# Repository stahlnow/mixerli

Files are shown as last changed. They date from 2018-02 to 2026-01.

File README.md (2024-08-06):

# mixerli

Battery powered 10 channel (4x2 + 1x2) stereo mixer featuring stereo input level control slider and stereo rotary aux send level control.

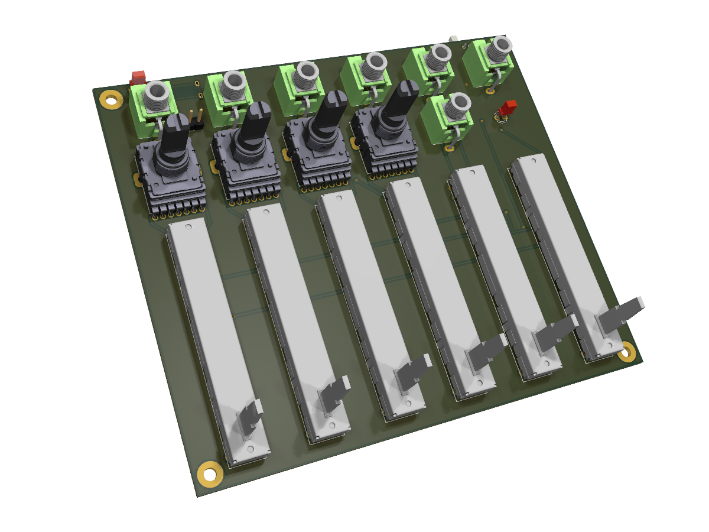
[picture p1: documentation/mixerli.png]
Mixerli


# Documentation

* [Build guide](documentation/build_guide.pdf)
* [Schematics](documentation/schematics/v2.0/mixerli_schematics_v2.0.1.pdf)

# License

SPDX-FileCopyrightText: 2023 Stahl office@stahlnow.com
SPDX-License-Identifier: CERN-OHL-S-2.0+

This source describes Open Hardware and is licensed under the CERN-OHL-S v2
or any later version.

You may redistribute and modify this source and make products using it
under the terms of the CERN-OHL-S v2 or any later version
(https://ohwr.org/cern_ohl_s_v2.txt).

This source is distributed WITHOUT ANY EXPRESS OR IMPLIED
WARRANTY, INCLUDING OF MERCHANTABILITY, SATISFACTORY
QUALITY AND FITNESS FOR A PARTICULAR PURPOSE. Please see
the CERN-OHL-S v2 for applicable conditions.

Source location: https://github.com/stahlnow/mixerli

As per CERN-OHL-S v2 section 4, should You produce hardware based
on this source, You must where practicable maintain the Source Location
visible on the printed circuit board of the mixerli or other products you make using this source.

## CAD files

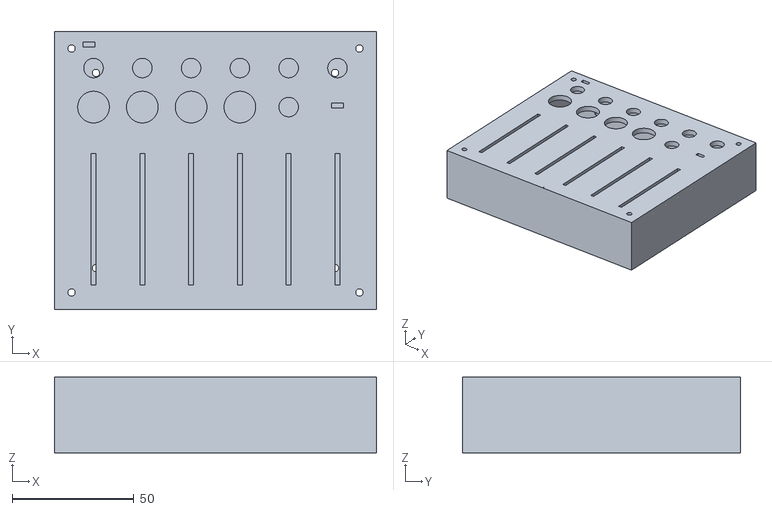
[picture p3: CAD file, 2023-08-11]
enclosure/v2.0/laser/mixerli_v2.0_case.stl
132.0 x 114.0 x 31.0

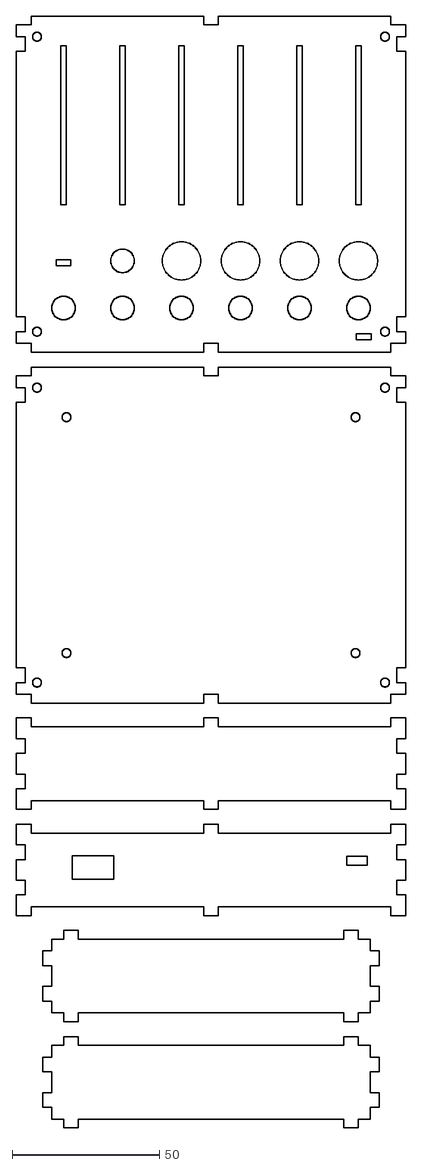
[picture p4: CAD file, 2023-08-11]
enclosure/v2.0/laser/output/mixerli_v2.0_case_laser_3mm.dxf
132.0 x 377.0

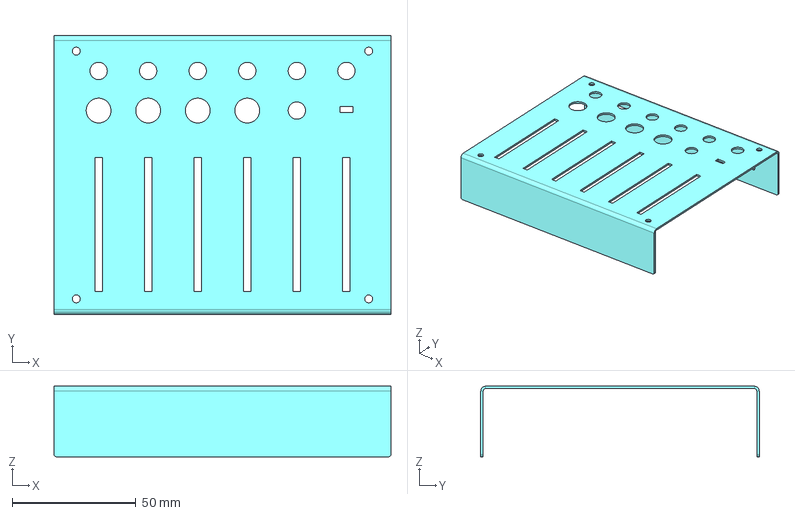
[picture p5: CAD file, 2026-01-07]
enclosure/v2.0/metalsheet/mixerli_v2.0.0-top.step
136.0 x 112.4 x 28.5 mm

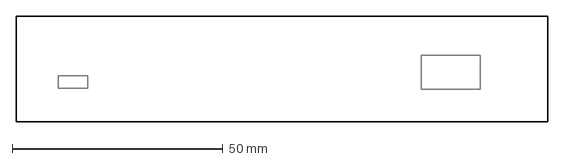
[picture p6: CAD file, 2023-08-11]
enclosure/v2.0/laser/mixerli_v2.0_back_cutout.dxf
126.0 x 25.0 mm

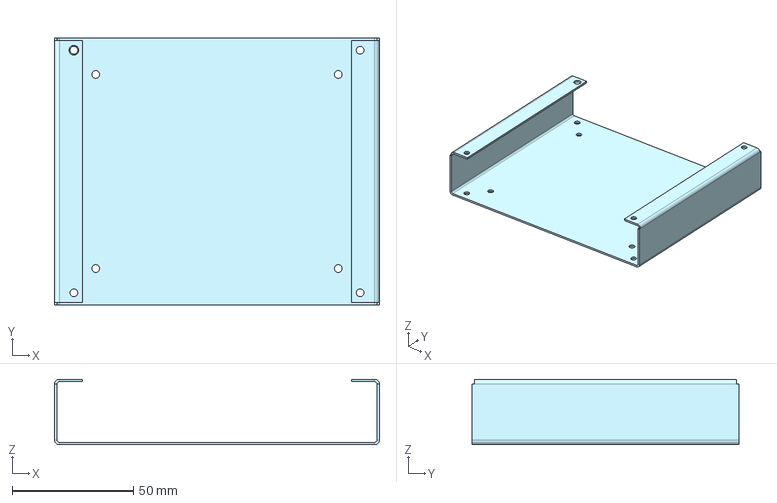
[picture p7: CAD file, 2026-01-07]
enclosure/v2.0/metalsheet/mixerli_v2.0.0-bottom.step
134.0 x 110.0 x 27.0 mm

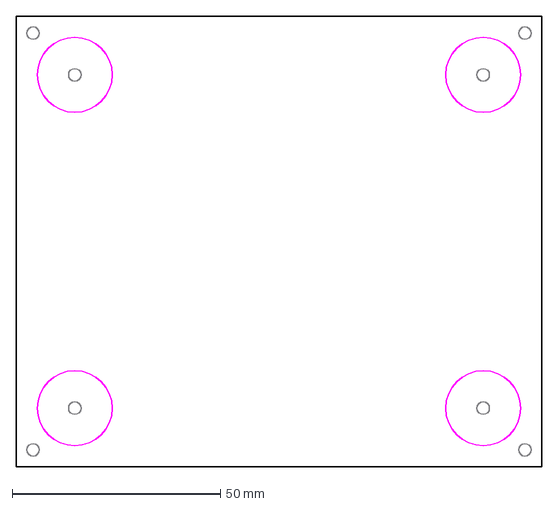
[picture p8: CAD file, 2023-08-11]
enclosure/v2.0/laser/mixerli_v2.0_bottom_cutout.dxf
126.0 x 108.0 mm

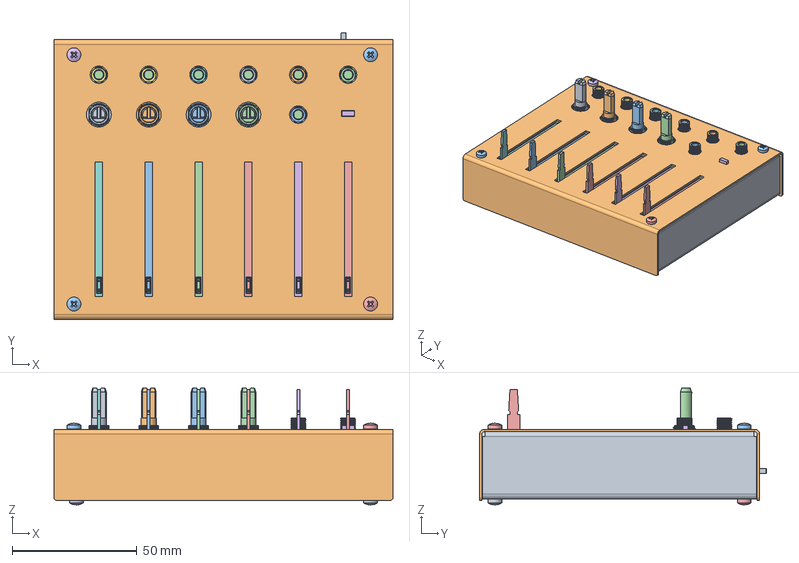
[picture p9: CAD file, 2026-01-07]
enclosure/v2.0/metalsheet/mixerli_v2.0.0.FCStd
136.0 x 115.1 x 46.9 mm
bottom
top
PJ366ST
PJ366ST002
ASSEMBLY
LED_Rectangular_W5.0mm_H2.0mm002
PJ366ST004
PJ366ST006
PJ366ST008
PJ366ST010
ASSEMBLY001
ASSEMBLY002
ASSEMBLY003
ASSEMBLY004
PJ366ST012
ASSEMBLY005
C_1206_3216Metric
C_1206_3216Metric002
C_1206_3216Metric004
C_1206_3216Metric006
C_1206_3216Metric008
C_1206_3216Metric010
C_1206_3216Metric012
CP_Elec_5x58
CP_Elec_5x059
C_1206_3216Metric014
C_1206_3216Metric016
C_1206_3216Metric018
C_1206_3216Metric020
CP_Elec_5x060
CP_Elec_5x061
CP_Elec_5x062
CP_Elec_5x063
C_1206_3216Metric022
C_1206_3216Metric024
C_1206_3216Metric026
C_1206_3216Metric028
C_1206_3216Metric030
C_1206_3216Metric032
CP_Elec_5x064
CP_Elec_5x065
C_1206_3216Metric034
C_1206_3216Metric036
C_1206_3216Metric038
C_1206_3216Metric040
CP_Elec_5x066
CP_Elec_5x067
C_1206_3216Metric042
C_1206_3216Metric044
C_1206_3216Metric046
C_1206_3216Metric048
CP_Elec_5x068
CP_Elec_5x069
C_1206_3216Metric050
C_1206_3216Metric052
C_1206_3216Metric054
C_1206_3216Metric056
C_1206_3216Metric058
C_1206_3216Metric060
R_1206_3216Metric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

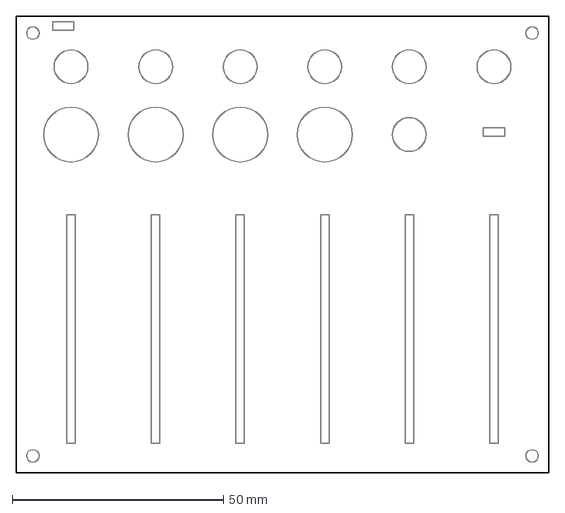
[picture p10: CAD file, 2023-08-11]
enclosure/v2.0/laser/mixerli_v2.0_top_cutout.dxf
126.0 x 108.0 mm

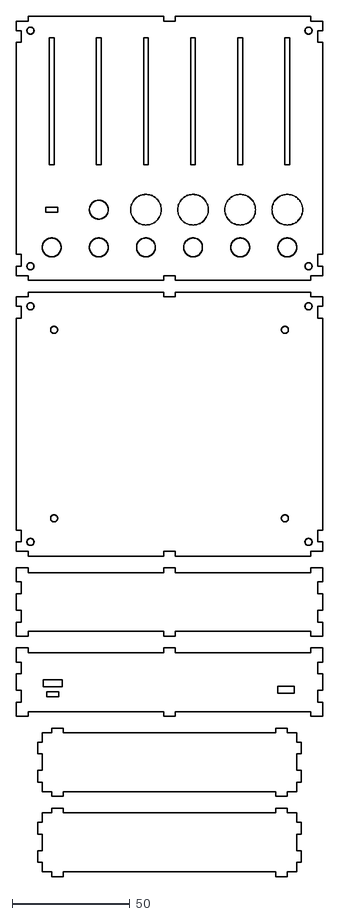
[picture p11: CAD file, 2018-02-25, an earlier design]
enclosure/v1.0/case/pocket_mixer_case_2mm.dxf
130.0 x 365.0

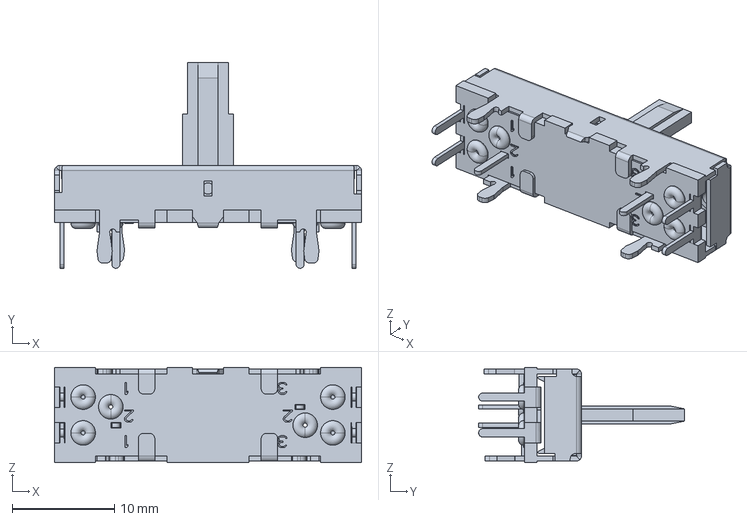
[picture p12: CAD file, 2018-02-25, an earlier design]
enclosure/v1.0/pta1544-2x10cixxxx.stp
30.0 x 20.1 x 9.30 mm

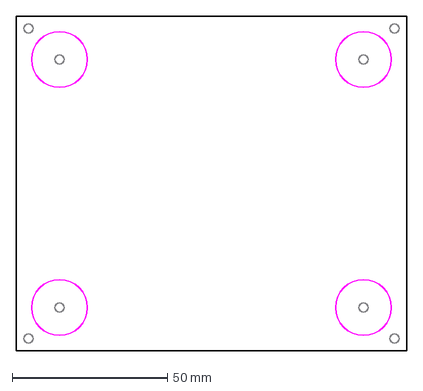
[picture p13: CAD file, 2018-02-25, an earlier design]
enclosure/v1.0/case/bottom_cutout.dxf
126.0 x 108.0 mm

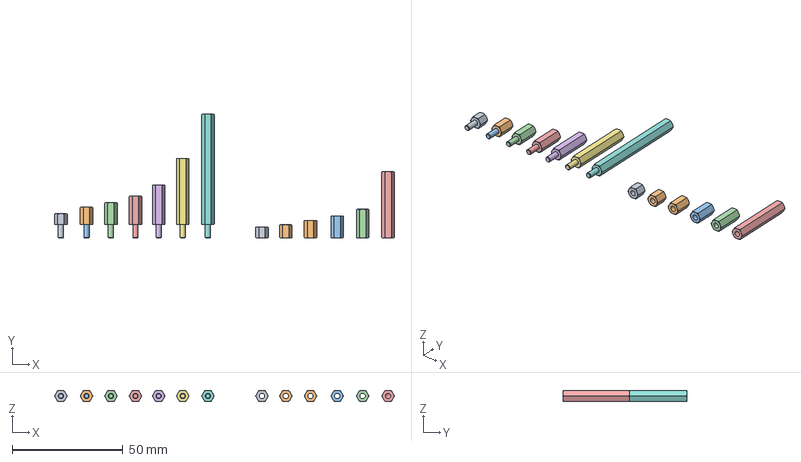
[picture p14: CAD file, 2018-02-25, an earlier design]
enclosure/v1.0/distans.stp
153.6 x 56.0 x 5.00 mm
OPT_DISTANSM3
DISTANSM3X10_VIDALI
DISTANSM3X10_VIDALI_1
DISTANSM3X10_VIDALI_2
DISTANSM3X18_VIDALI
DISTANSM3X30_VIDALI
DISTANSM3X50_VIDALI
DISTANSM3X5
DISTANSM3X10_VIDALI_3
DISTANSM3X10_VIDALI_4
DISTANSM3X10_VIDALI_5
DISTANSM3X10_VIDALI_6
DISTANSM3X30_DISI_DISI

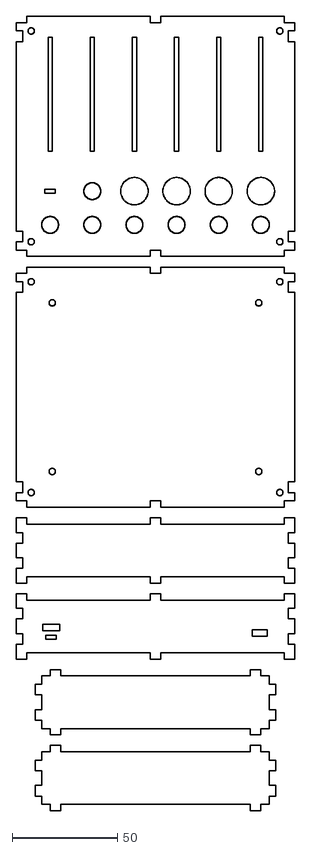
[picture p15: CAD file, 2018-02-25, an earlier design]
enclosure/v1.0/case/pocket_mixer_case_3mm.dxf
132.0 x 377.0

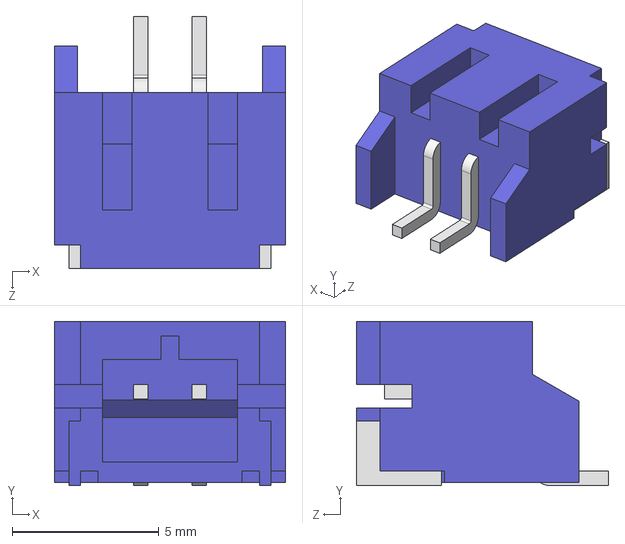
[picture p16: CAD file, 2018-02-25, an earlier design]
enclosure/v1.0/S2B-PH-SM4-TB.STEP
7.90 x 5.60 x 8.60 mm

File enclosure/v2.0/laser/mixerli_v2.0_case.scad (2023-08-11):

/*
mixer case
by stahl
[office@stahlnow.com]

released under the permissive MIT license

file history
v1.0 - born
*/

/*********************************************** START OF USER VARIABLES */
// what to build
laser = false;  // set to true for laser cut rendering
render(laser);

// define inner volume in mm
length = 108;
width = 126;
height = 25; // thing + spacer + extra space

thickness = 3; // thickness of material

// slots configuration
slots = true; // make slots?

// overlap of top/bottom panels in mm
overlap = 0;
// round edge or not (applies only if overlap > 0)
round_edges = true;

// slots configuration
num_slots_right_left = 2;       // number of slots >= 0
slot_width_right_left = 5;     // width of slot
slot_clearance_right_left = 4;  // inset to slot >= 0, add plus or minus 0.1 if last tooth is missing
num_slots_front_back = 3;       
slot_width_front_back = 5;
slot_clearance_front_back = 0.0;  // inset to slot >= 0, add plus or minus 0.1 if last tooth is missing

// t-joints configuration
t_joints_front = false;
t_joints_back = false;
t_joints_right = false;
t_joints_left = false;
t_joints_top_bottom = false;

num_t_joints = 1; // number of t-joints
bolt_size = 3; // bolt size in mm (M2,M3,M4,M5, etc.)
bolt_length = 13; // bolt length in mm

// clearence between panel edge and t-joint
// could be set to a number instead of calculation
t_joints_top_left_clearance = length/(2*num_t_joints); 
t_joints_right_left_clearance = height/(2*num_t_joints);
t_joints_front_back_clearance = width/(2*num_t_joints);

joints_inset = 2; // clearance between panel edge and hole
nut_size = 7.5;// M3: 5.5, M4: 7.2, M5: 8.0
nut_thickness = 3.5;// M3: 2.4, M4: 3.5 M5: 5.6

// clearance for laser cutting in mm
laser_clearance = 5;

// colors
col_alpha = 0.8;
col_top =  "DarkGrey";
col_bottom = "DarkGrey";
col_left = "Yellow";
col_right = col_left;
col_front = "LightBlue";
col_back = "Green";

// number of fragments for round edges
$fn = 100;

glitch_corr = 0.1; // visual glitch correction (careful, this will mess with dimensions!)

/************************************************* END OF USER VARIABLES */
module render(laser) {
    if (laser) {
        laser();
    } else {
        3d();
    }
}

module 3d() {
    /*
    color("Yellow", 0.9)
    rotate([0, 0, 0])
    translate([57.5, -20.5,2.5])
    import("mixerli_v2.0.stl");
    */
    
    top();
    bottom();
    front();
    back();
    left();
    right();
}

module laser() {
    glitch_corr = 0.0; // set glitch correction to zero
    // top
    rotate([0, 0, 180])
    if (slots) {
        projection() difference() {
            top();
            right();
            left();
            slots_front_back(-(length+thickness)/2.0);
            slots_front_back((length+thickness)/2.0);
        }
    } else {
        projection() mirror([1,0,0]) top();
    }

    // bottom
    bottom_offset = -(length+2*thickness+2*overlap+laser_clearance);
    translate([0,bottom_offset,0])
    rotate([0, 0, 180]) mirror([1,0,0])
    
    if (slots) {
        projection() difference() {
            bottom();
            right();
            left();        
            slots_front_back(-(length+thickness)/2.0);
            slots_front_back((length+thickness)/2.0);
        }
    } else {
        projection() bottom();
    }
    
    // front
    front_offset = bottom_offset-(length+height)/2-overlap-2*thickness-laser_clearance;
    projection() translate([0,front_offset,0]) rotate([-90,0,180])
    
    if (slots) {
        difference() {
            front();
            slots_right_left(-(width+thickness)/2);
            slots_right_left((width+thickness)/2);
        }
    } else {
        projection() front();
    }
    
    
    // back
    back_offset = front_offset-height-2*thickness-laser_clearance;
    projection() translate([0,back_offset,0]) rotate([-90,0,180]) mirror([1,0,0]) 
    if (slots) {
        difference() {
            back();
            slots_right_left(-(width+thickness)/2);
            slots_right_left((width+thickness)/2);
        }
    } else {
        projection() back();
    }

    // left
    left_offset = back_offset-height-2*thickness-laser_clearance;
    projection() translate([0,left_offset,0]) rotate([0,90,90]) left();
    
    // right
    right_offset = left_offset-height-2*thickness-laser_clearance;
    projection() translate([0,right_offset,0]) rotate([0,90,90]) right();
    
}


module top() {
    if (round_edges) {
        p = 0;
    } else {
        p = overlap;
    }
    
    difference() {
        union() color(col_top, col_alpha) {
            minkowski()
            {
                translate([0,0, (height+thickness)/2])
                if (!round_edges) {
                    cube([width+2*thickness+overlap, length+overlap+2*thickness, thickness-0.01], center=true);
                } else {
                    cube([width+2*thickness, length+2*thickness, thickness-0.01], center=true);
                }
                if (round_edges) cylinder(r=overlap, h=0.001, $fn=100);
            }
        }
        t_joints_holes_top_bottom();
        t_joints_holes_front_back();       
        // cutouts
        color("silver")
        translate([0.0, 0.0, (height-thickness)/2])
        linear_extrude(thickness*3)
        import(file = "mixerli_v2.0_top_cutout.dxf", layer = "0");
        // engraving
        color("white")
        translate([0.0, 0.0, height/2])
        linear_extrude(thickness)
        import(file = "mixerli_v2.0_top_cutout.dxf", layer = "engraving");
    }
}

module bottom() {
    if (round_edges) {
        p = 0;
    } else {
        p = overlap;
    }
    
    difference() {
        union() color(col_bottom, col_alpha) {
            minkowski()
            {
                translate([0,0, -(height+thickness)/2])
                if (!round_edges) {
                    cube([width+2*thickness+overlap, length+overlap+2*thickness, thickness-0.01], center=true);
                } else {
                    cube([width+2*thickness, length+2*thickness, thickness-0.01], center=true);
                }
                if (round_edges) cylinder(r=overlap, h=0.001, $fn=100);
            }
        }
        t_joints_holes_top_bottom();
        t_joints_holes_front_back();
        // cutouts
        color("silver")
        mirror([1,0,0]) translate([0.0, 0.0, -height/2-1.5*thickness])
        linear_extrude(thickness*2)
        import(file = "mixerli_v2.0_bottom_cutout.dxf", layer = "0");
        // engraving
        color("white")
        mirror([1,0,0]) translate([0.0, 0.0, -height/2-thickness])
        linear_extrude(thickness)
        import(file = "mixerli_v2.0_bottom_cutout.dxf", layer = "engraving");
    }
   
}

module front() { 
    difference() {
        union() color(col_front, col_alpha) {
            translate([0.0, -(length+thickness)/2.0, 0.0])
            cube([width+2.0*thickness, thickness, height], center=true);
            // slots
            if (slots)
                slots_front_back(-(length+thickness)/2.0);
        }
        
        // t-joints
        if (t_joints_front)
            t_joints_front_back(-(length+thickness)/2.0);
        // t-joints holes (on the side)
        t_joints_holes_right_left();
        
        // cutouts
        color("silver")
        translate([0,-length/2+thickness,0]) 
        rotate([90,0,0])
        linear_extrude(thickness*3)
        import(file = "mixerli_v2.0_front_cutout.dxf", layer = "0");
        // engraving
        color("white")
        translate([0,-length/2,0]) 
        rotate([90,0,0])
        linear_extrude(thickness)
        import(file = "mixerli_v2.0_front_cutout.dxf", layer = "engraving");        
    }
}

module back() {
    difference() {
        union()
        color(col_back, col_alpha) {
            translate([0.0, (length + thickness)/2.0, 0.0])
            cube([width+2.0*thickness, thickness, height], center=true);
            if (slots)
                slots_front_back((length+thickness)/2.0);
        }
        
        // t-joints
        if (t_joints_back)
            t_joints_front_back((length+thickness)/2.0);
        // t-joints holes (on the side)
        t_joints_holes_right_left();
        
        // cutouts
        color("silver")
        mirror([1,0,0]) rotate([90,0,0]) translate([0,0,-(length/2)-1.5*thickness]) 
        linear_extrude(thickness*2)
        import(file = "mixerli_v2.0_back_cutout.dxf", layer = "0");
        // engraving
        color("White")
        mirror([1,0,0]) rotate([90,0,0]) translate([0,0,-(length/2)-1.5*thickness]) 
        linear_extrude(thickness*3)
        import(file = "mixerli_v2.0_back_cutout.dxf", layer = "engraving");
    }
}

module t_joints_holes_right_left() {
    if (t_joints_left)
        t_joints_right_left(-(width+thickness)/2.0+joints_inset, true);
    if (t_joints_right)
        t_joints_right_left((width+thickness)/2.0-joints_inset, true);
}
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

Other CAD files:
enclosure/v1.0/case/top_cutout.dxf
enclosure/v1.0/case/back_cutout.dxf
enclosure/v1.0/Turn knob.STEP
enclosure/v1.0/1050170001.stp
enclosure/v1.0/case/pocket_mixer_case.scad

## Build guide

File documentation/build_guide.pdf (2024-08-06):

Battery powered 10 channel (4x2 + 1x2) stereo mixer featuring stereo input level control slider and stereo rotary aux send level control.

# Mixerli

Builder's Guide for v2.0
Source Location: github.com/stahlnow/mixerli

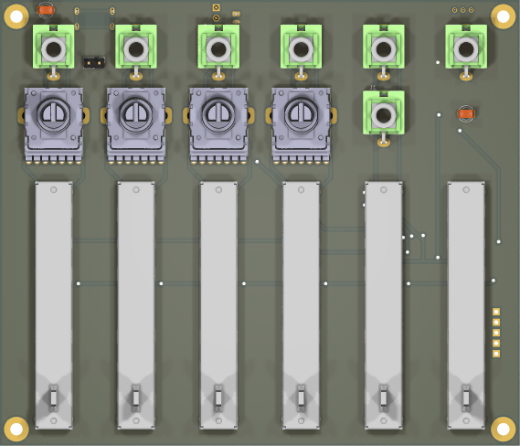
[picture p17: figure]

SPDX-FileCopyrightText: 2023 Stahl office@stahlnow.com SPDX-License-Identifier: CERN-OHL-S-2.0+

This source describes Open Hardware and is licensed under the CERN-OHL-S v2 or any later version.

You may redistribute and modify this source and make products using it under the terms of the CERN-OHL-S v2 or any later version (https://ohwr.org/cern_ohl_s_v2.txt).

This source is distributed WITHOUT ANY EXPRESS OR IMPLIED WARRANTY, INCLUDING OF MERCHANTABILITY, SATISFACTORY QUALITY AND FITNESS FOR A PARTICULAR PURPOSE. Please see the CERN-OHL-S v2 for applicable conditions.

Source location: https://github.com/stahlnow/mixerli

As per CERN-OHL-S v2 section 4, should You produce hardware based on this source, You must where practicable maintain the Source Location visible on the printed circuit board of the mixerli or other products you make using this source.

# Operation

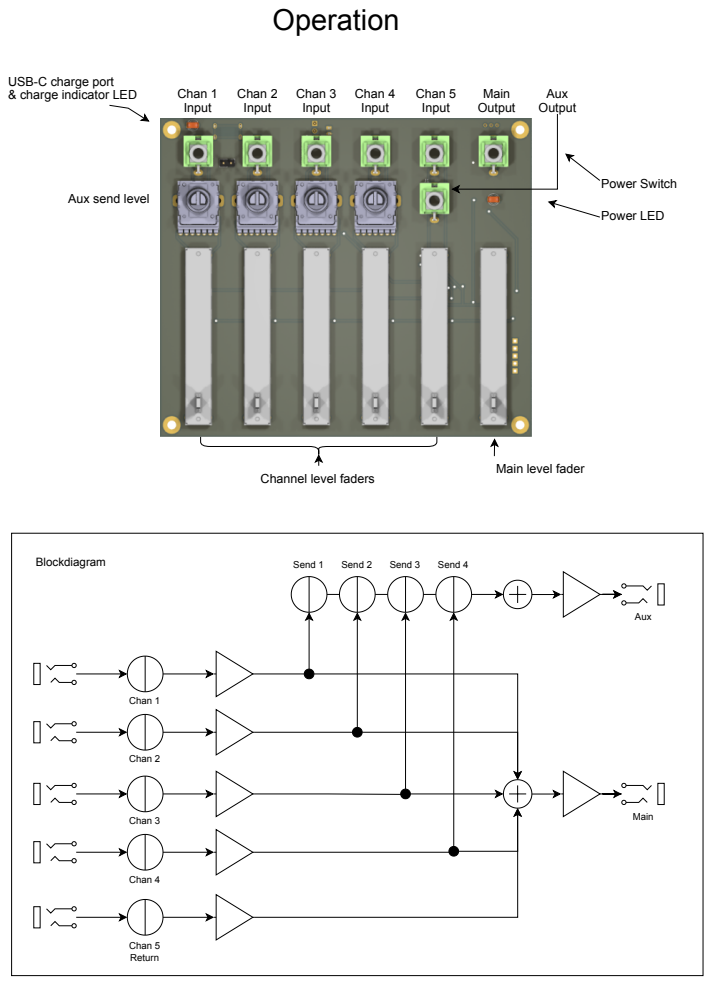
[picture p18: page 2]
Chan 1; Send 1; Chan 2; Send 2; Chan 3; Send 3; Chan 4; Send 4; Chan 5 Return; Aux; Main; Chan 5 Input; Power LED; Main Output; & charge indicator LED; Input; Chan 2 Input; Chan 3 Input; Chan 4 Input; Aux Output; Power Switch; Blockdiagram

USB-C charge port

Aux send level

Main level fader

Channel level faders

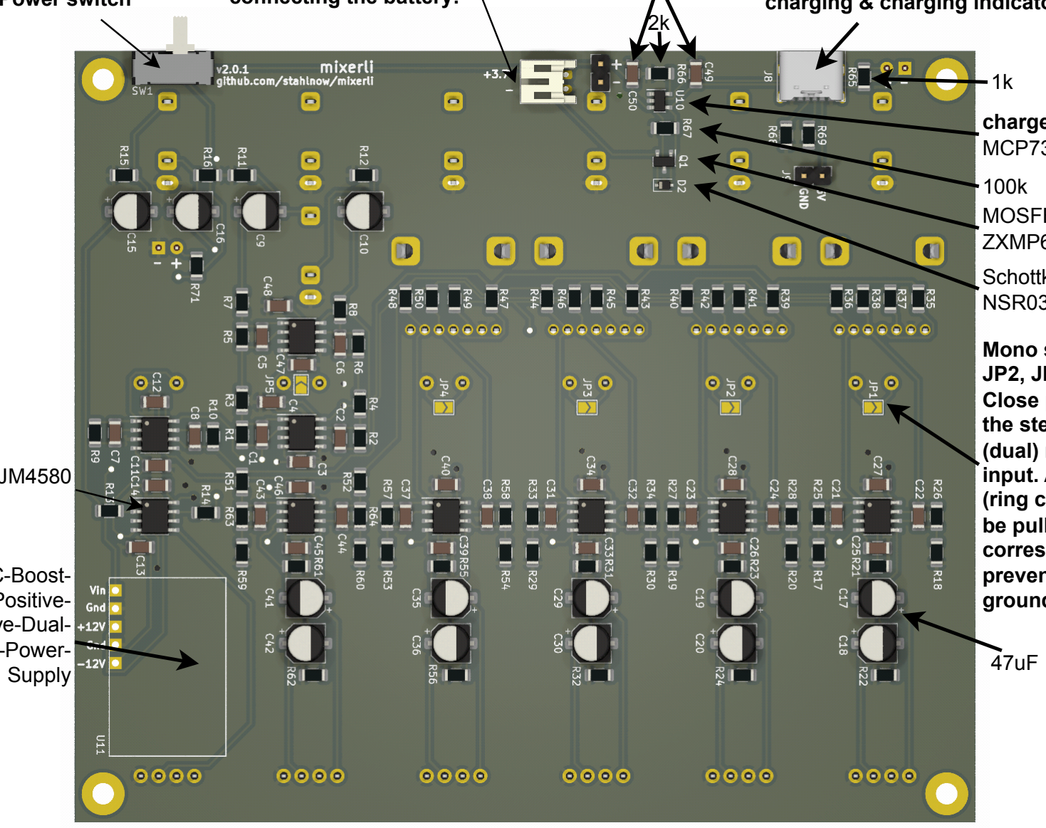
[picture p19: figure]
Supply

charge controller
MCP73831

Schottky diode
NSR0320MW2T3G

MOSFET
ZXMP6A13FTA

100k

4.7uF

1k

NJM4580

USB-C for powering and battery charging & charging indicator LED

Mono solder pads (JP1,
JP2, JP3, JP4):
Close pad X to convert
the stereo input X to a
(dual) monophonic
input. Additonally, pin 2
(ring contact) needs to
be pulled from the
corresponding jack to
prevent shorting to
ground.

DC-DC-Boost-Converter-Positive-Negative-Dual-Output-Power-

JST connector for battery. Connect to a 3.7v lithium polymer battery. Double check polarity before
Power switch | connecting the battery!

Please use ibom for easy pick & place.

# Build

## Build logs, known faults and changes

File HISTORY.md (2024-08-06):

# v2.0.1

- fixed pulldown resistors on CC lines

# v2.0.0

- usb c type connector
- power supply module
- new potentiometers and jacks

erratum

- power only works with USB type A cable, fix for type C cable: put 5.1k pulldown resistors on the two USB CC lines

# v1.0.0

- first version with μ usb

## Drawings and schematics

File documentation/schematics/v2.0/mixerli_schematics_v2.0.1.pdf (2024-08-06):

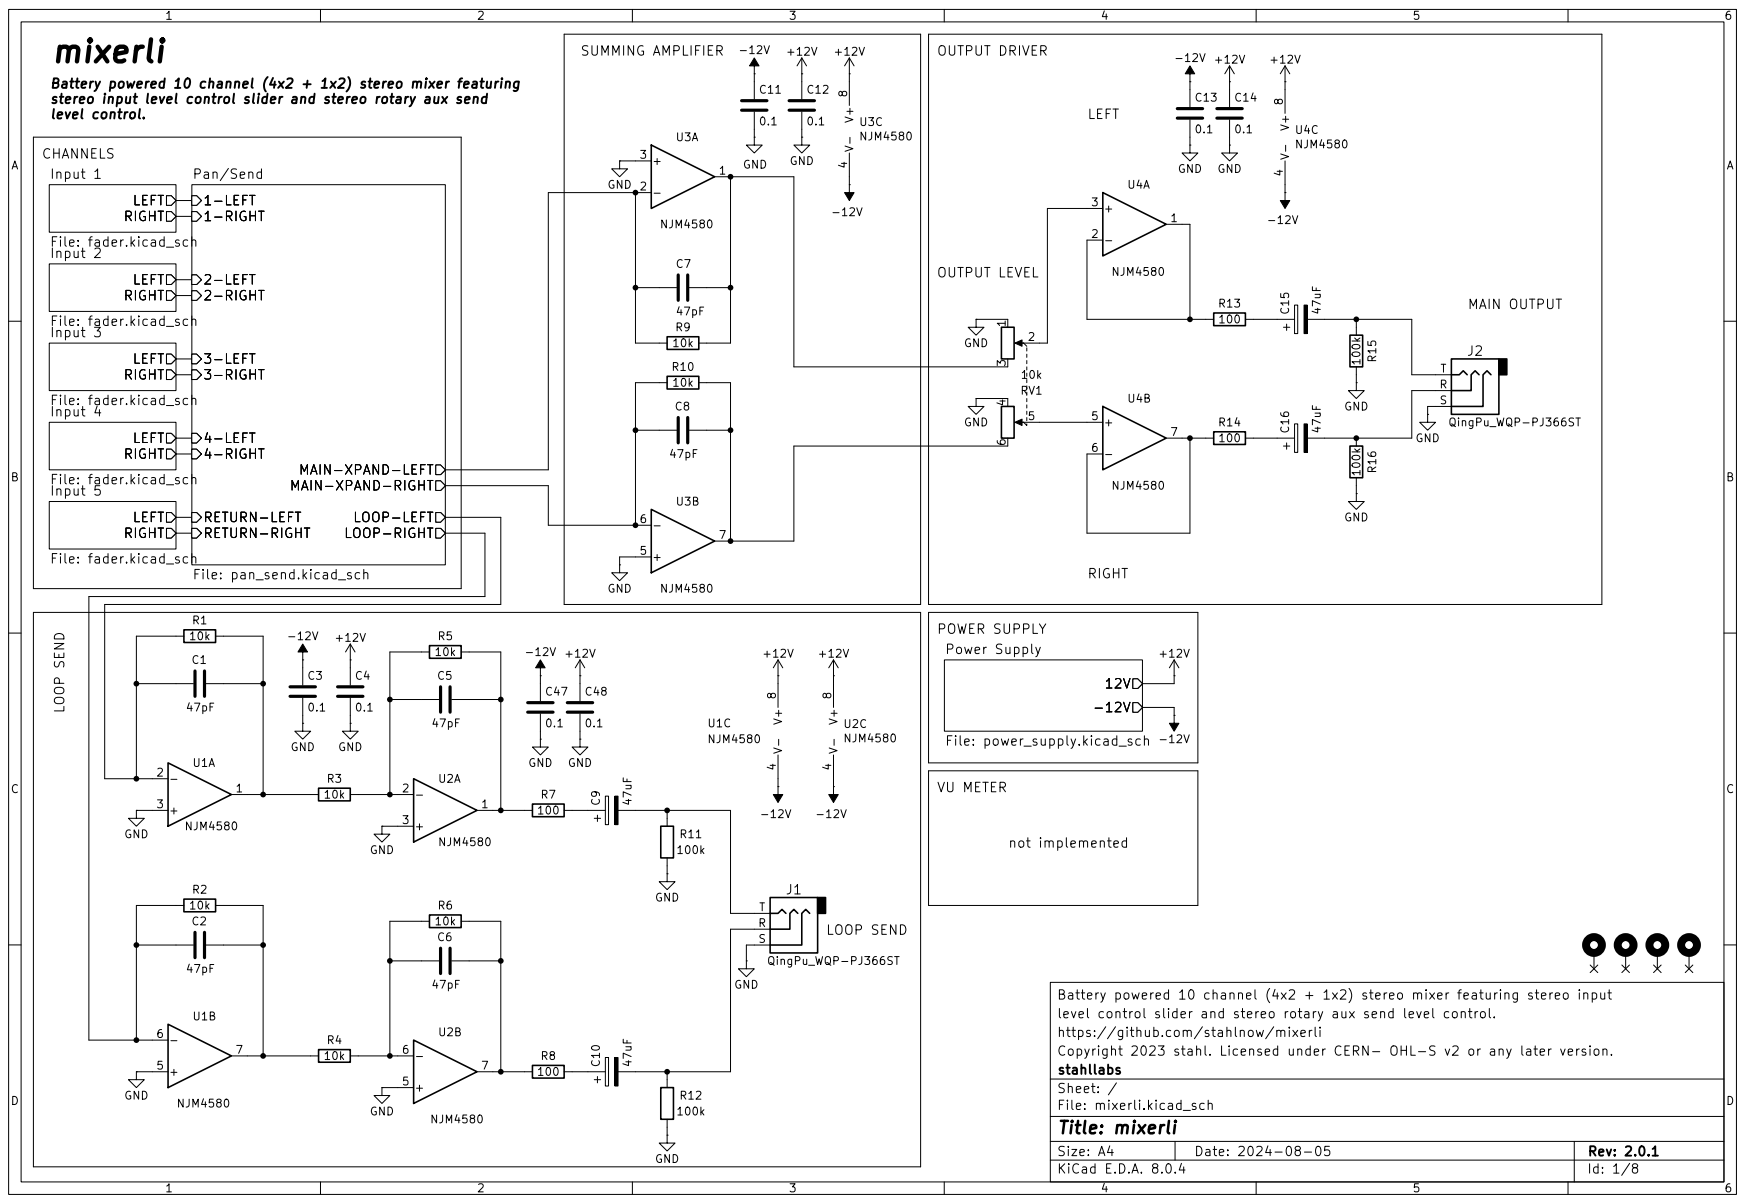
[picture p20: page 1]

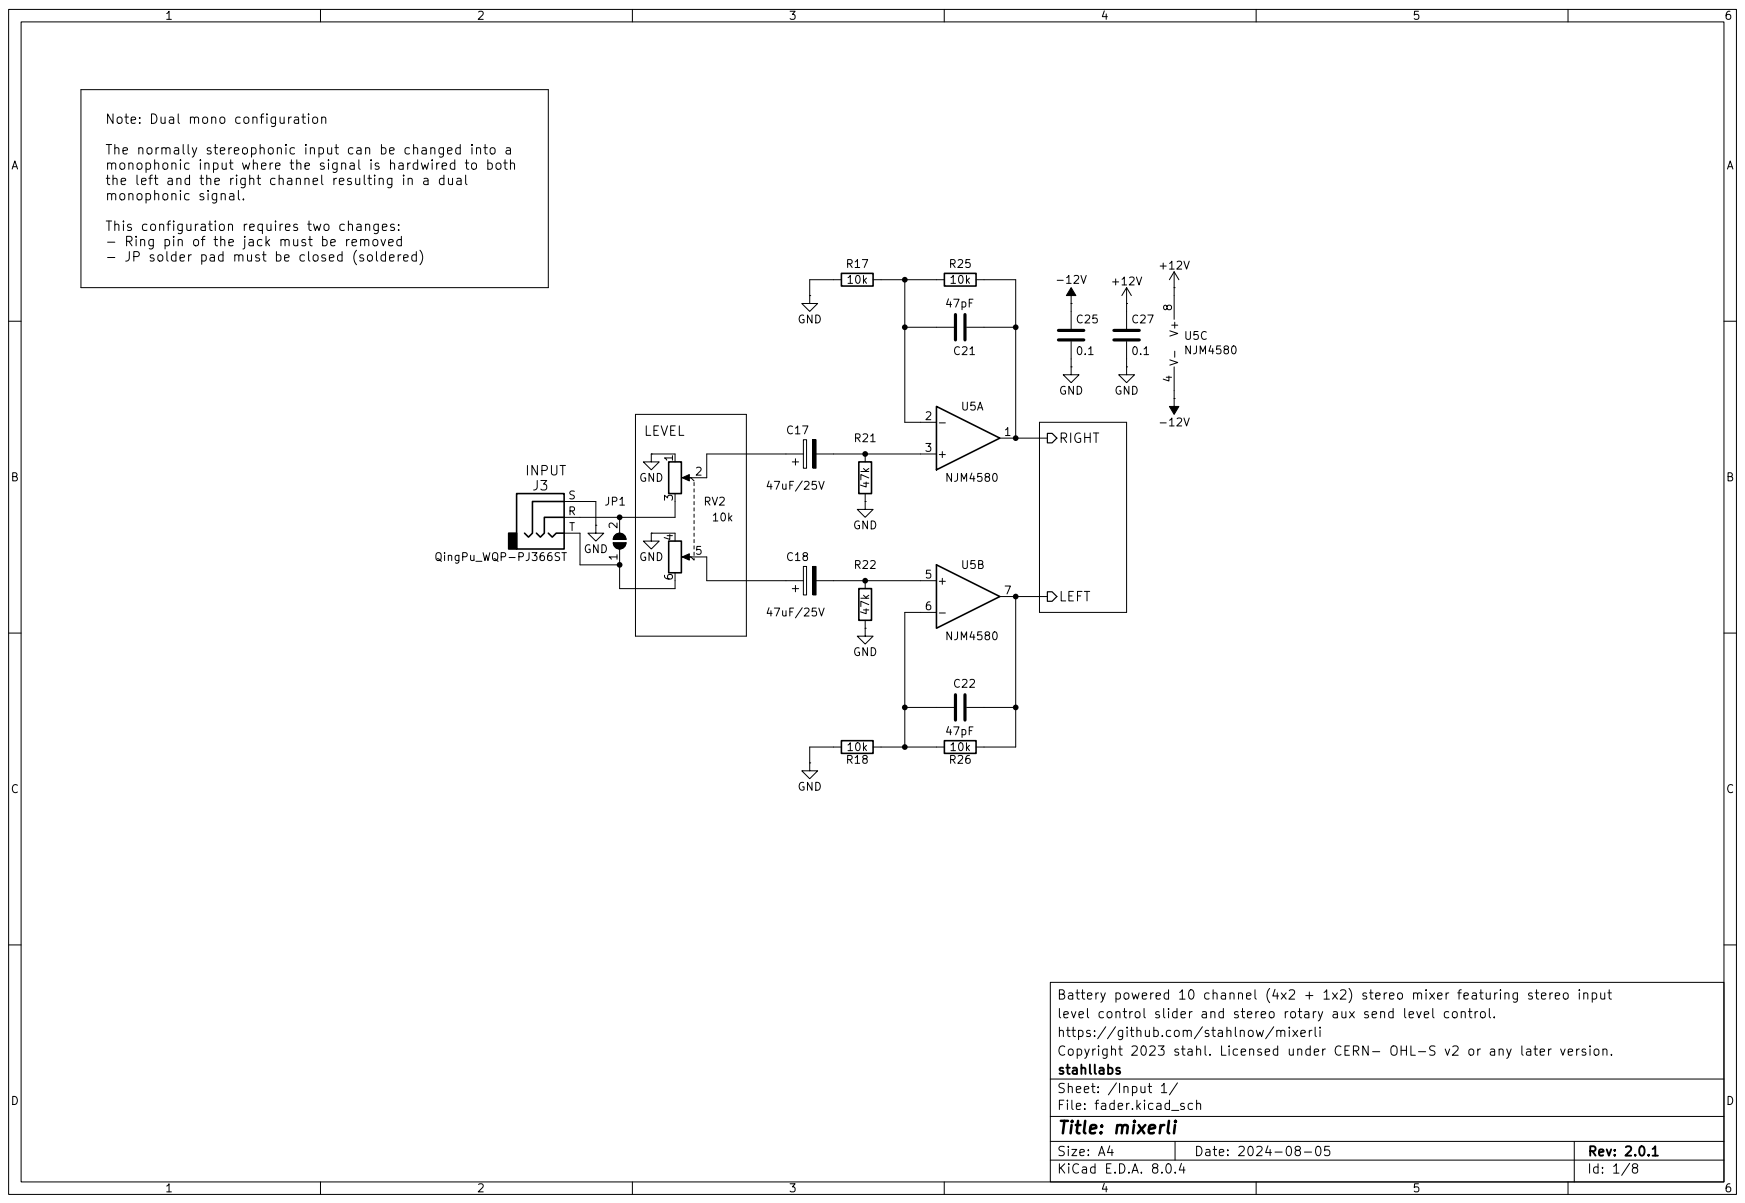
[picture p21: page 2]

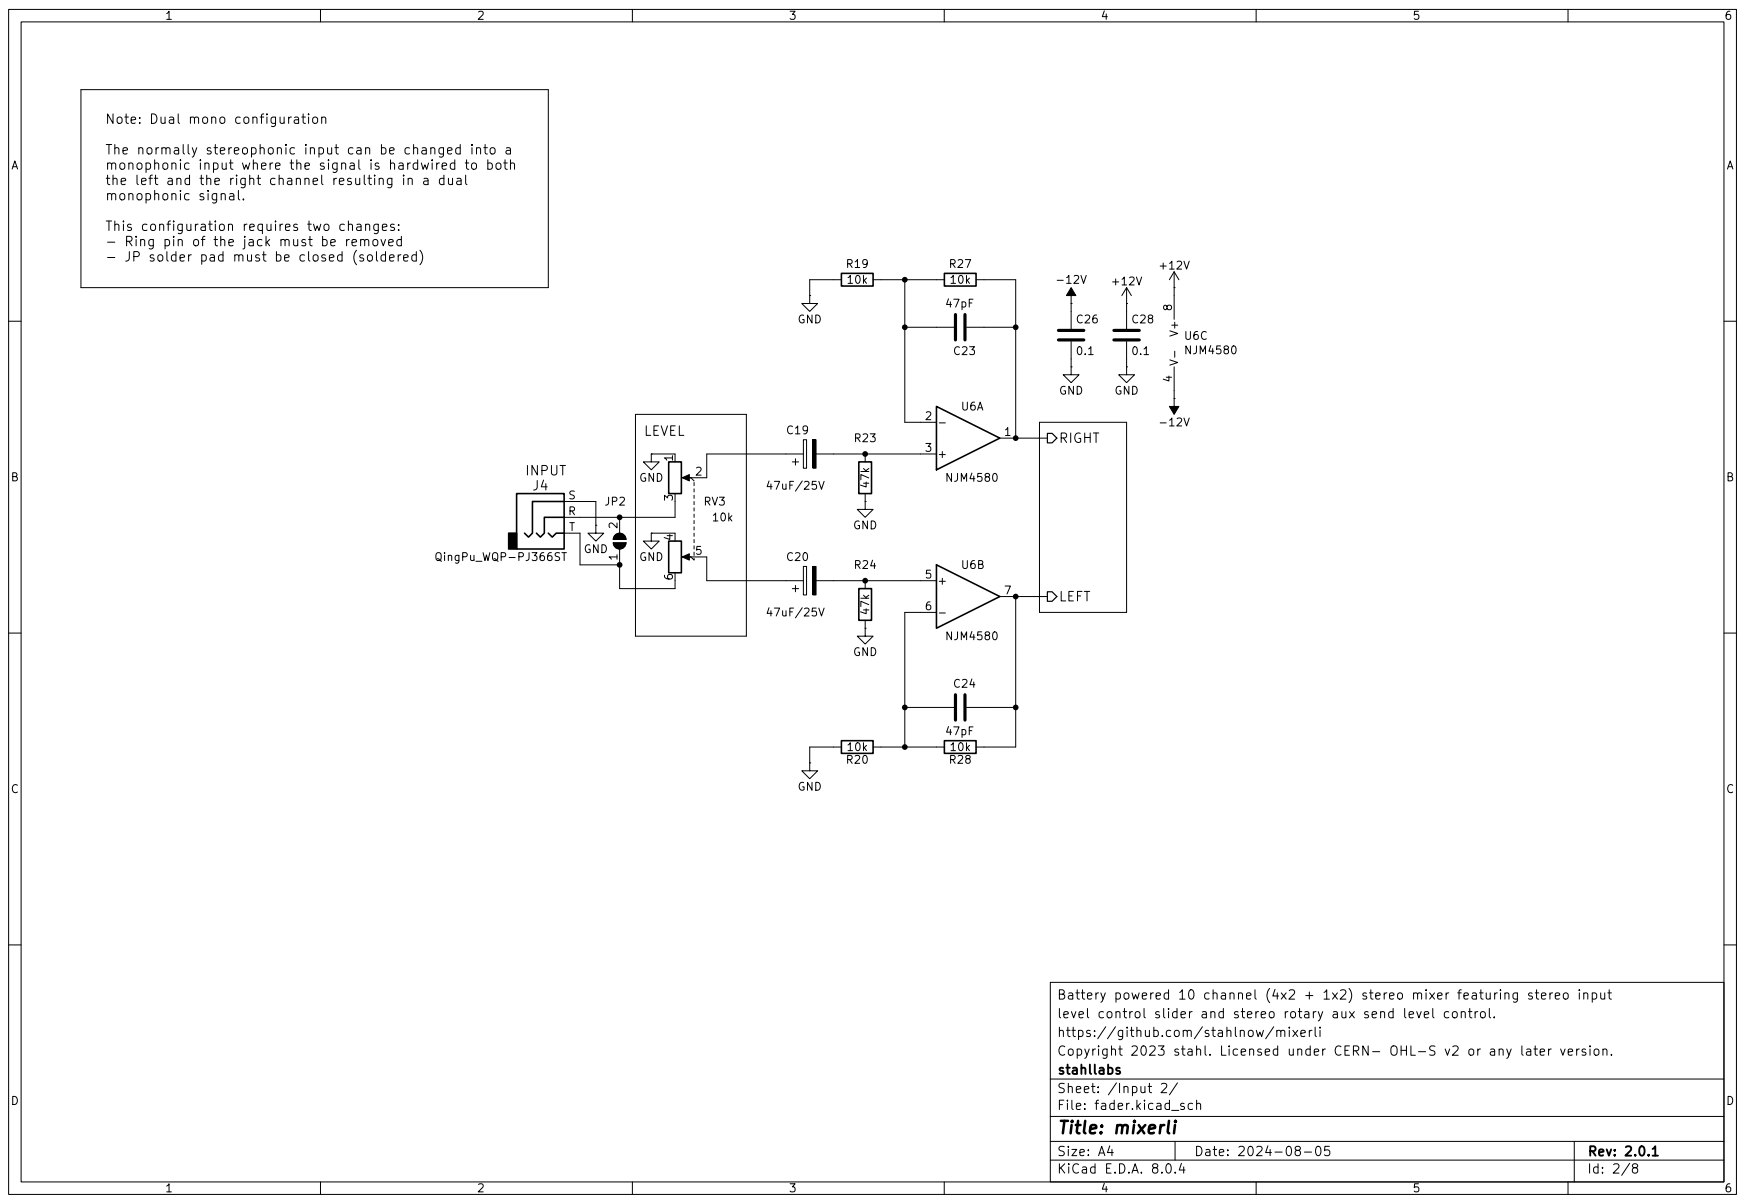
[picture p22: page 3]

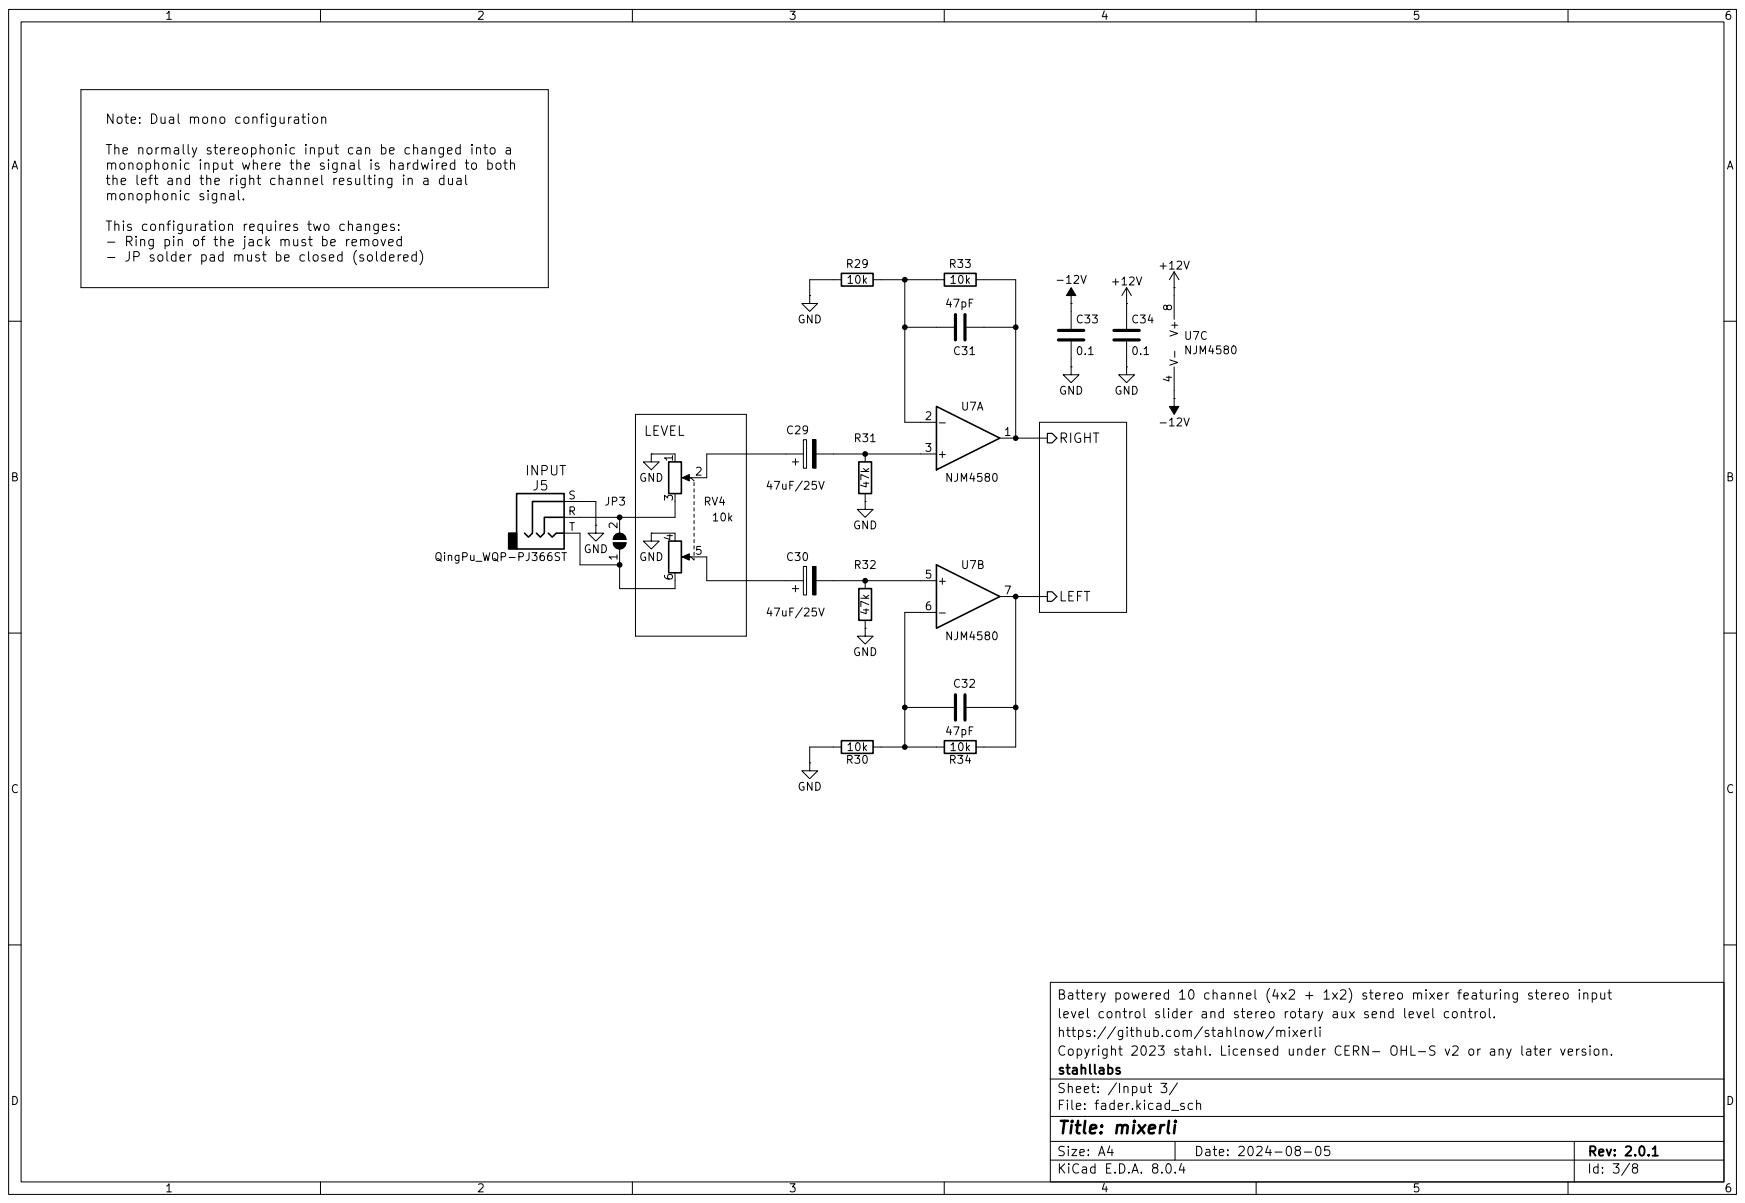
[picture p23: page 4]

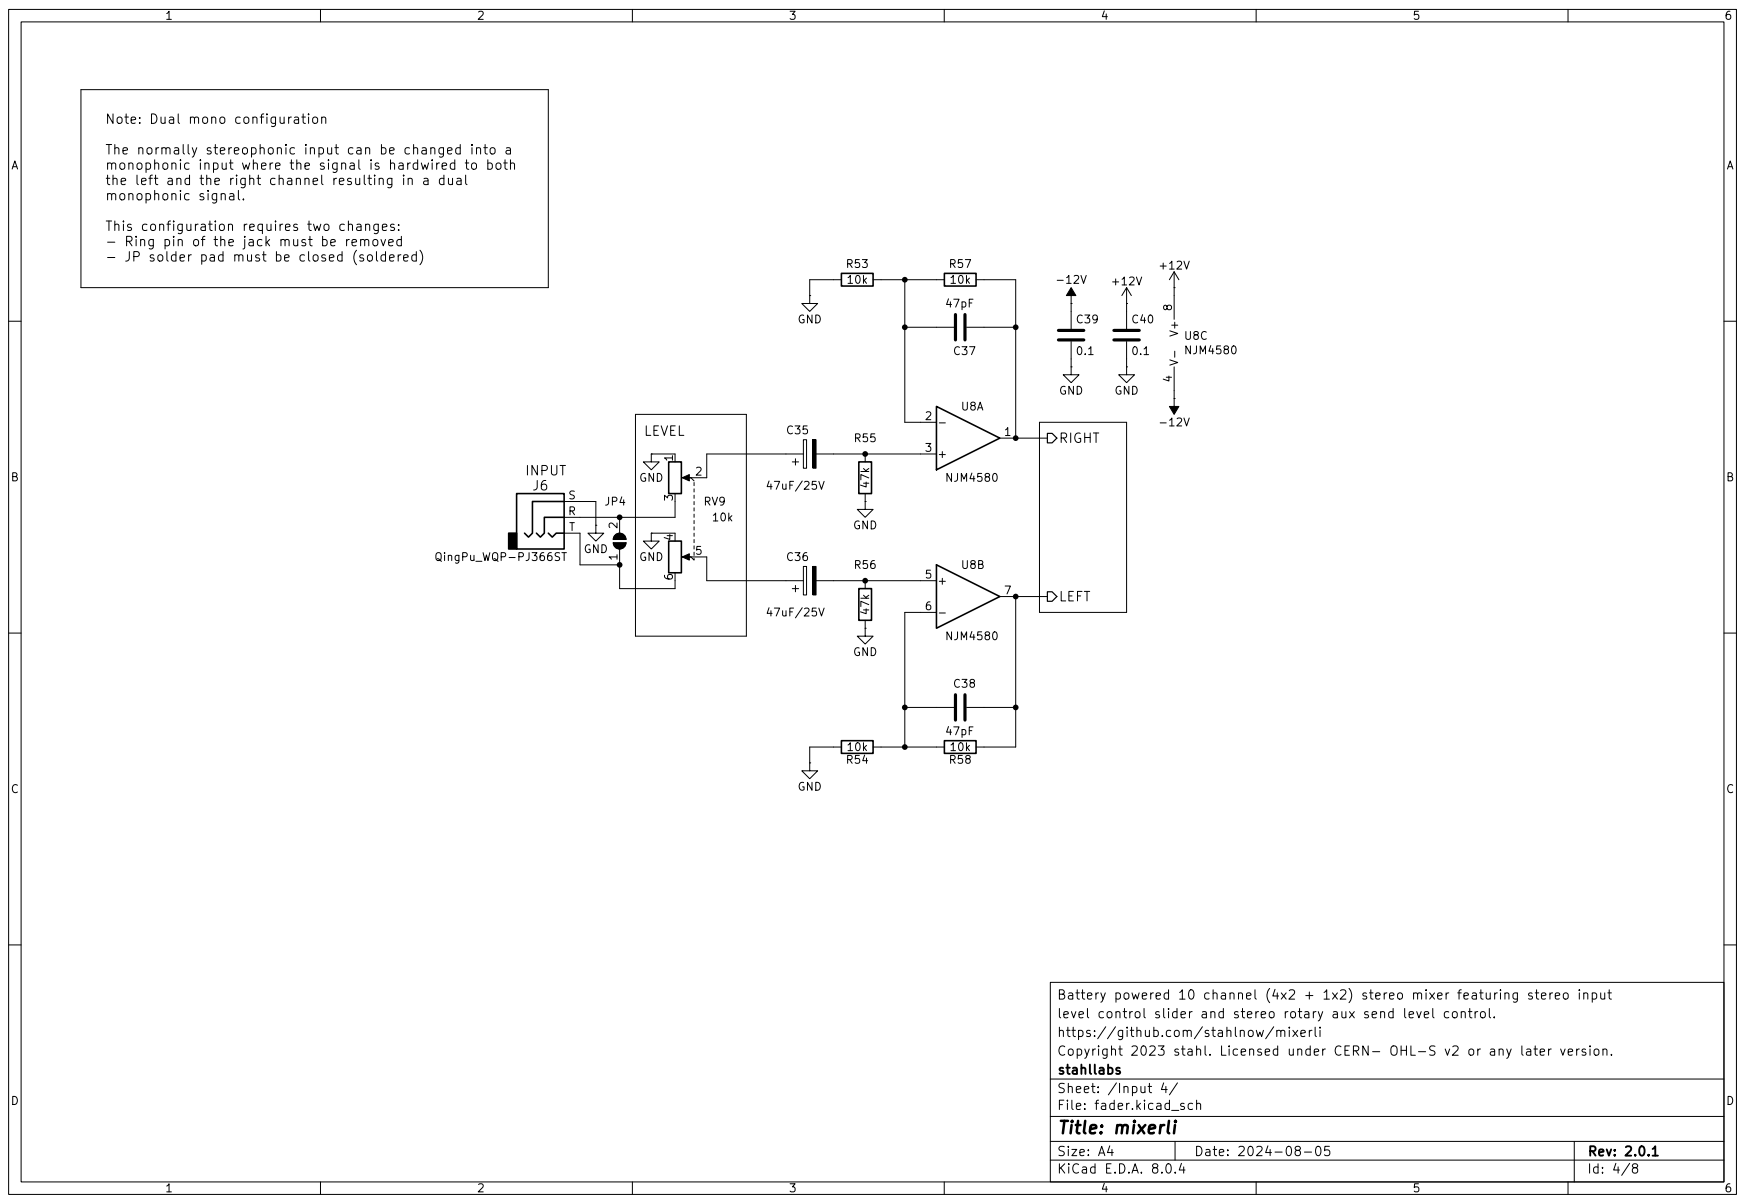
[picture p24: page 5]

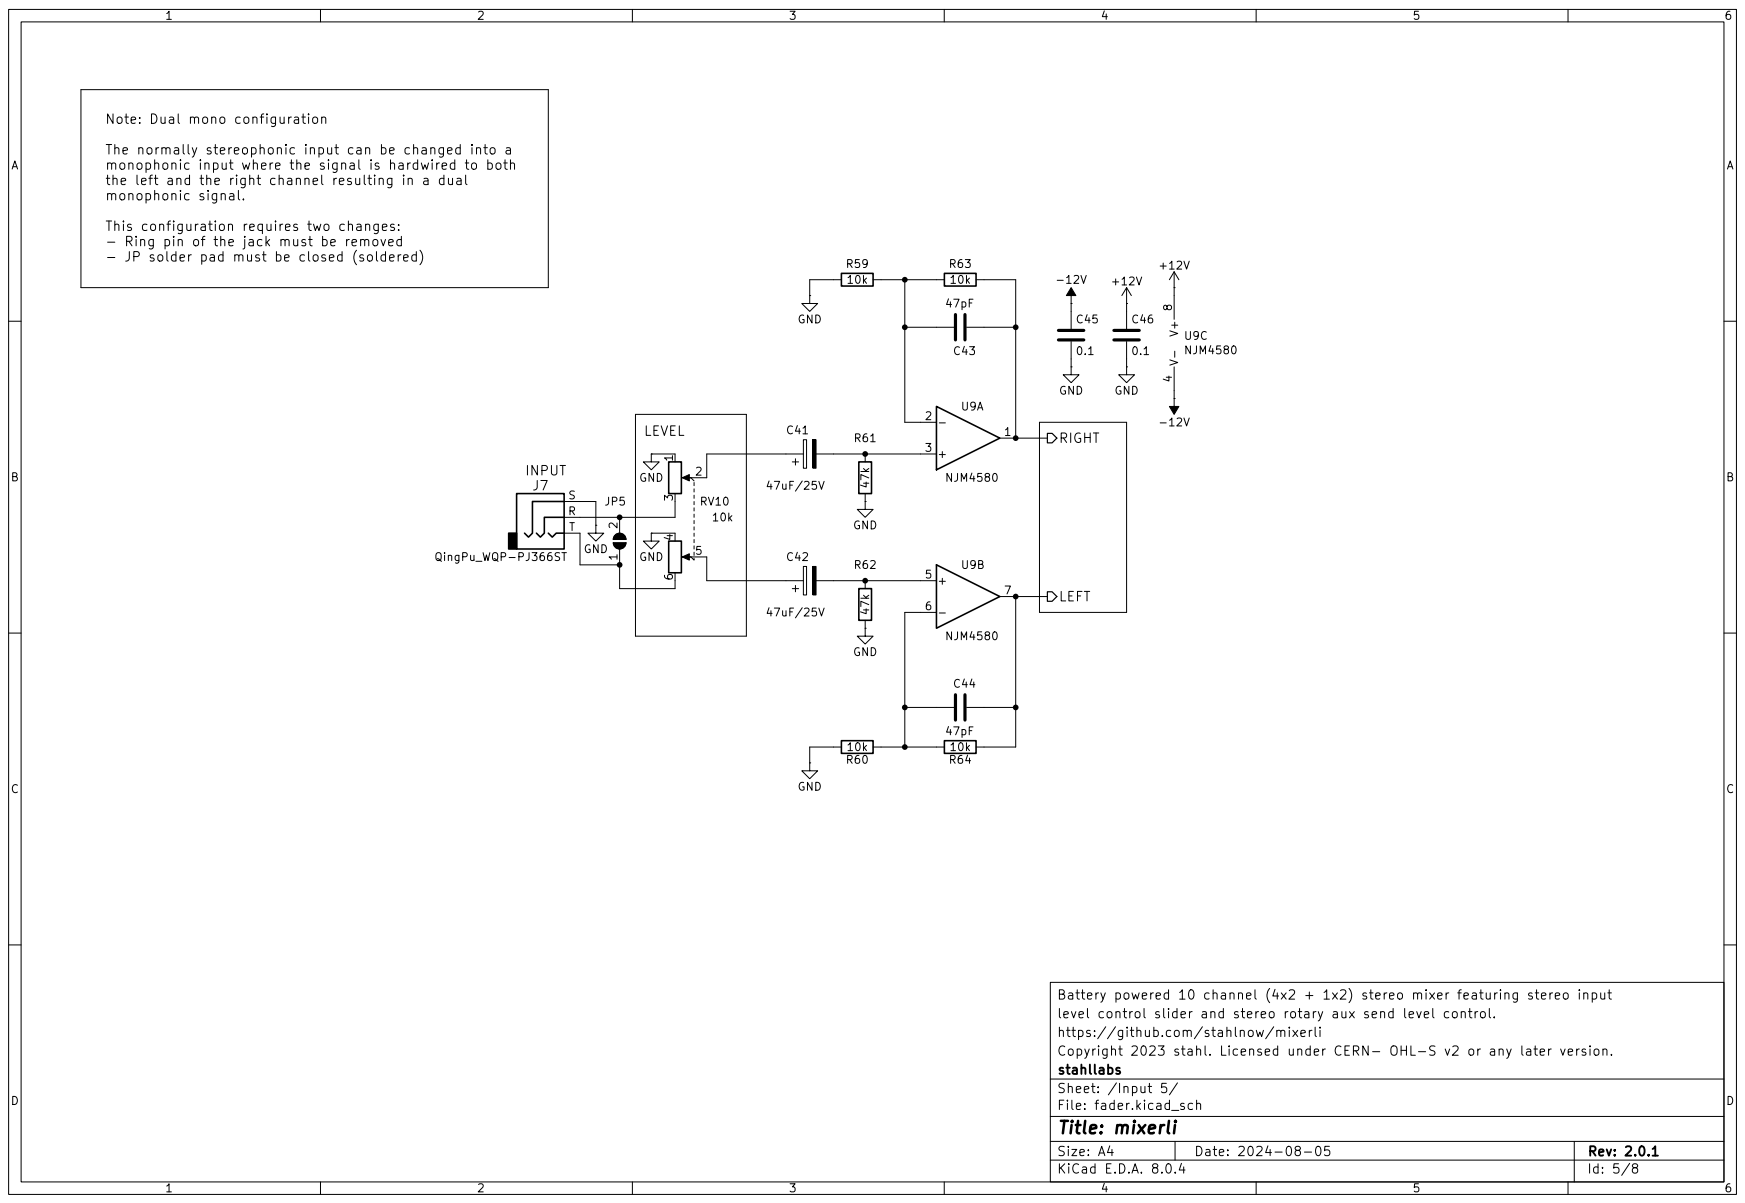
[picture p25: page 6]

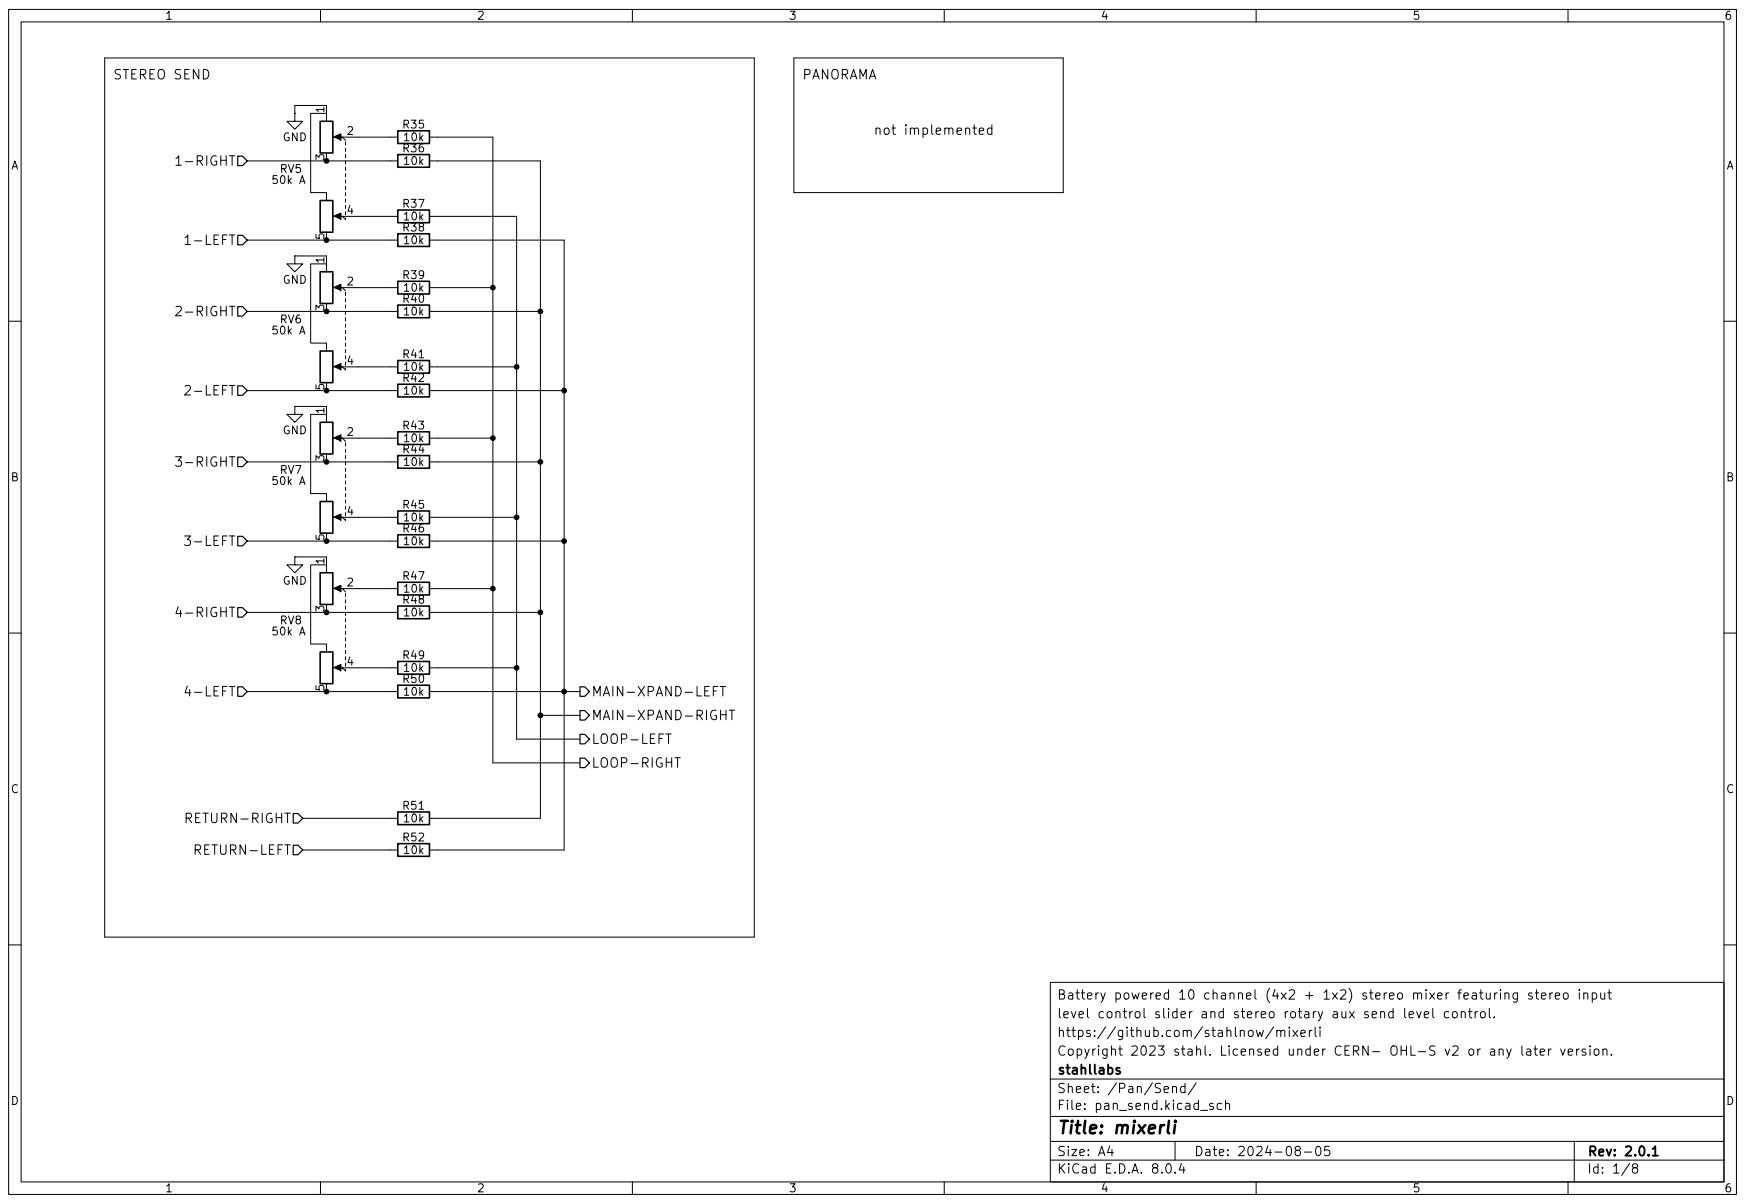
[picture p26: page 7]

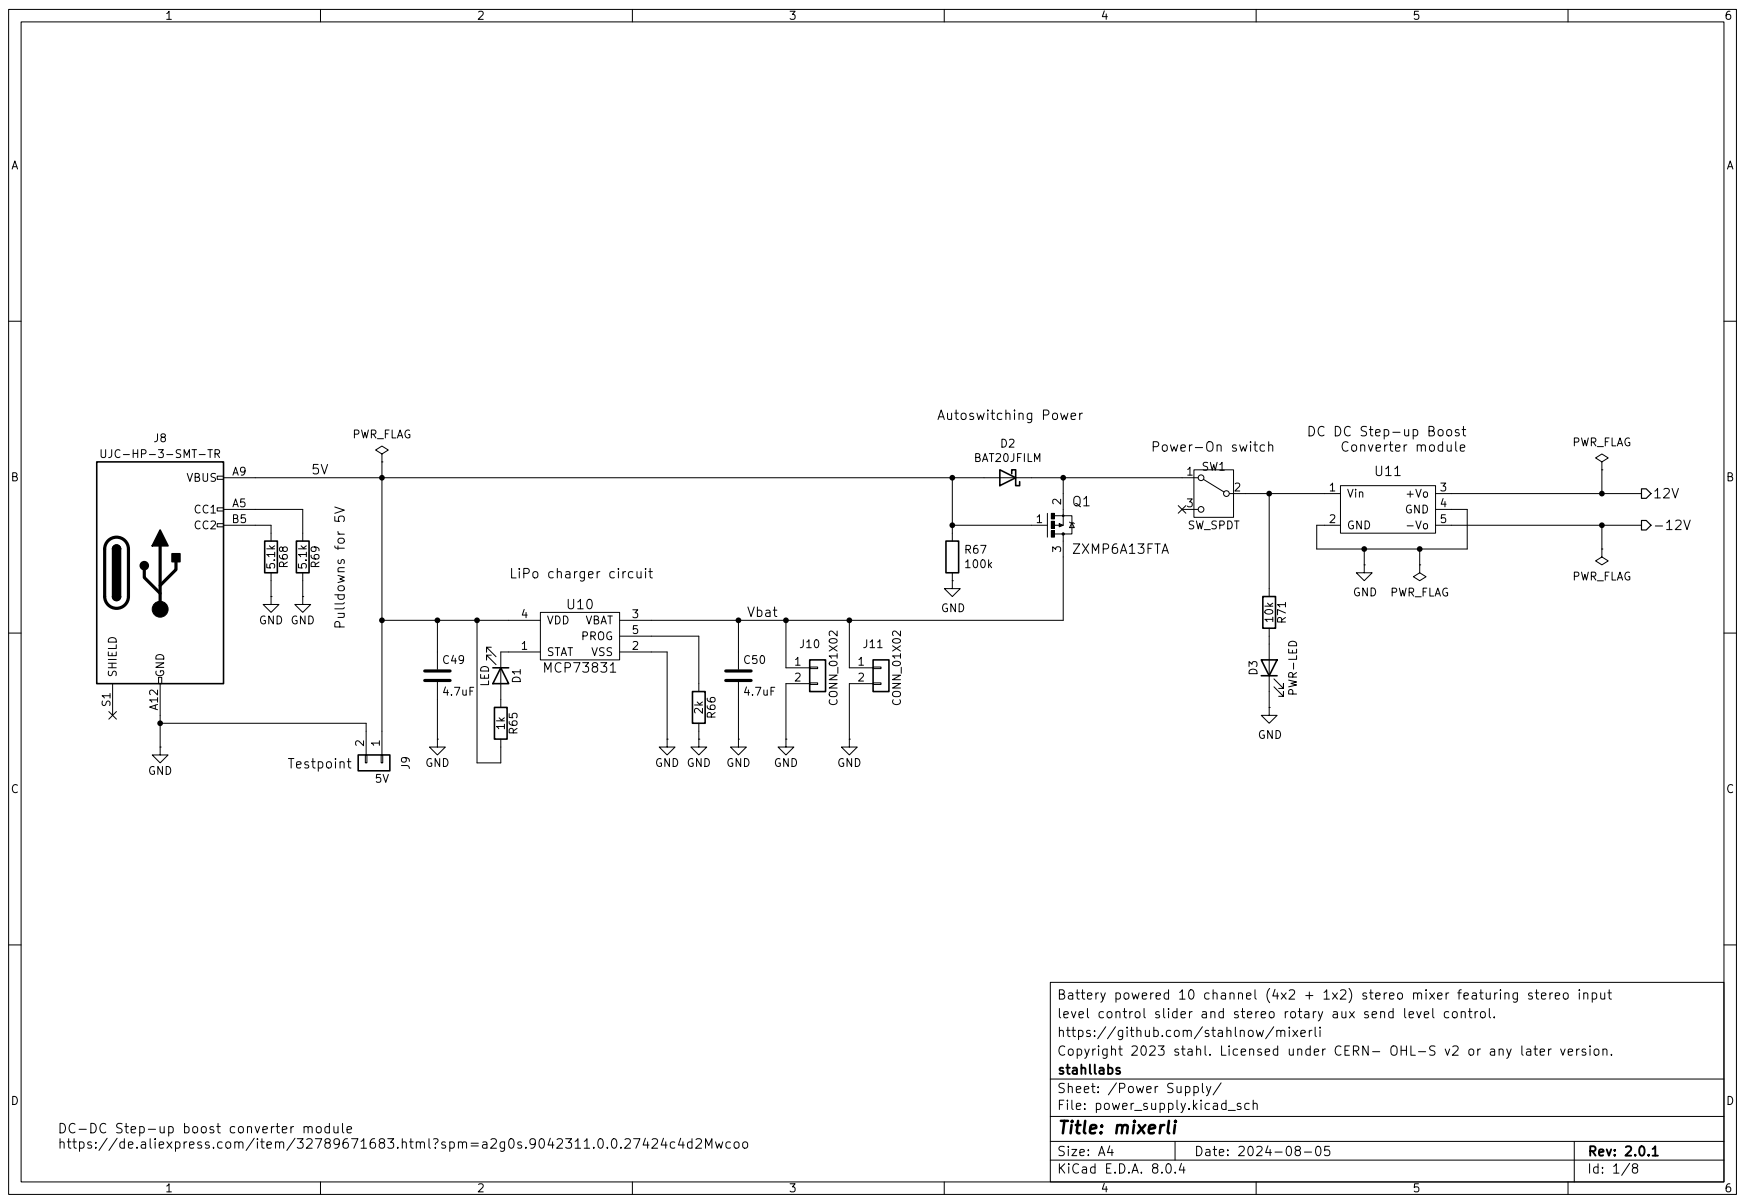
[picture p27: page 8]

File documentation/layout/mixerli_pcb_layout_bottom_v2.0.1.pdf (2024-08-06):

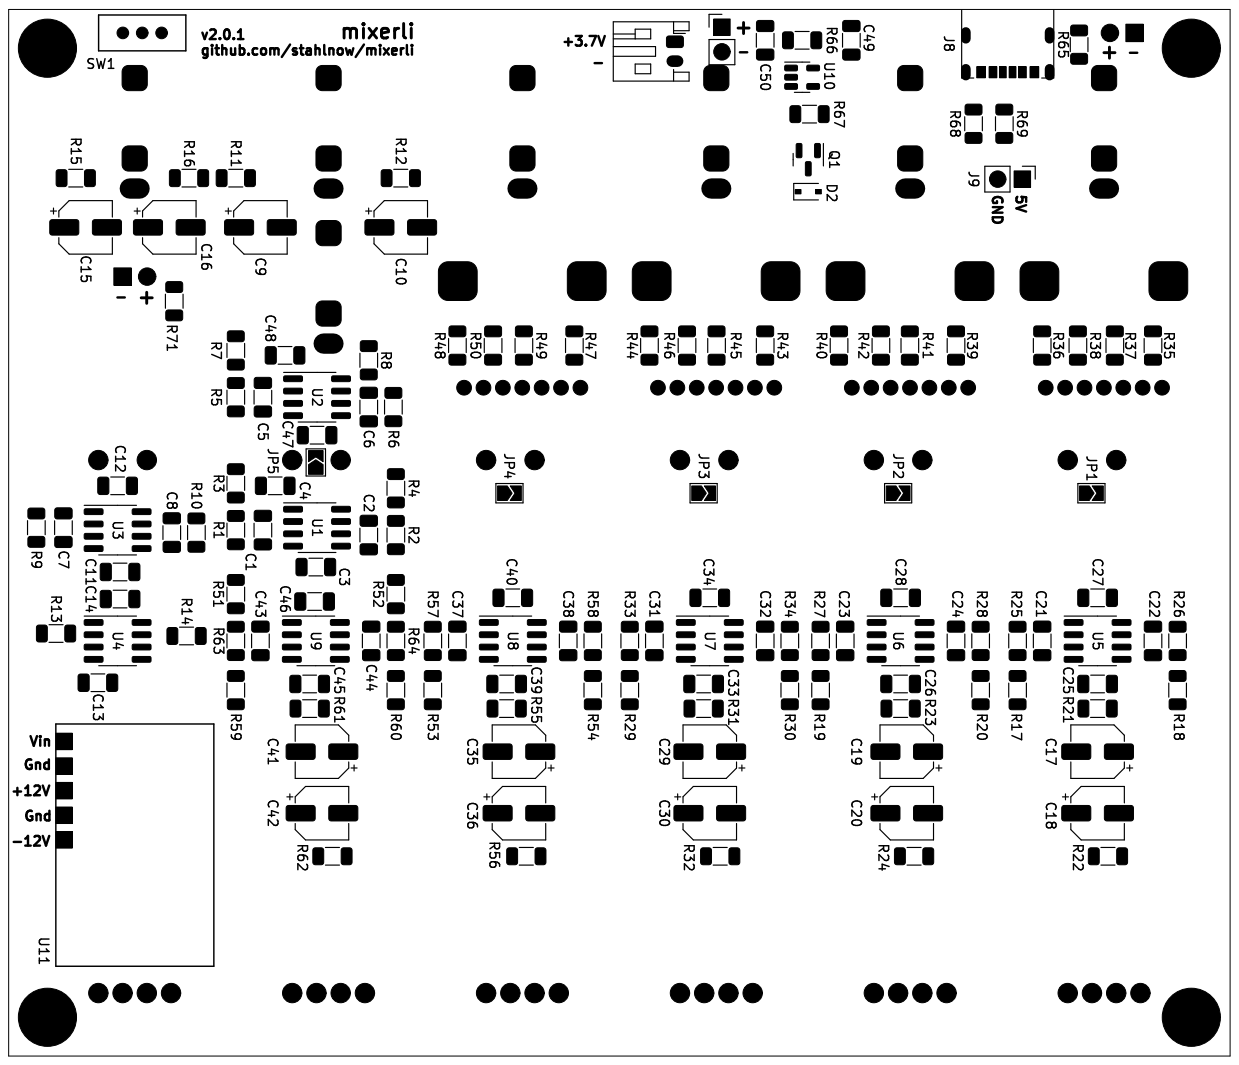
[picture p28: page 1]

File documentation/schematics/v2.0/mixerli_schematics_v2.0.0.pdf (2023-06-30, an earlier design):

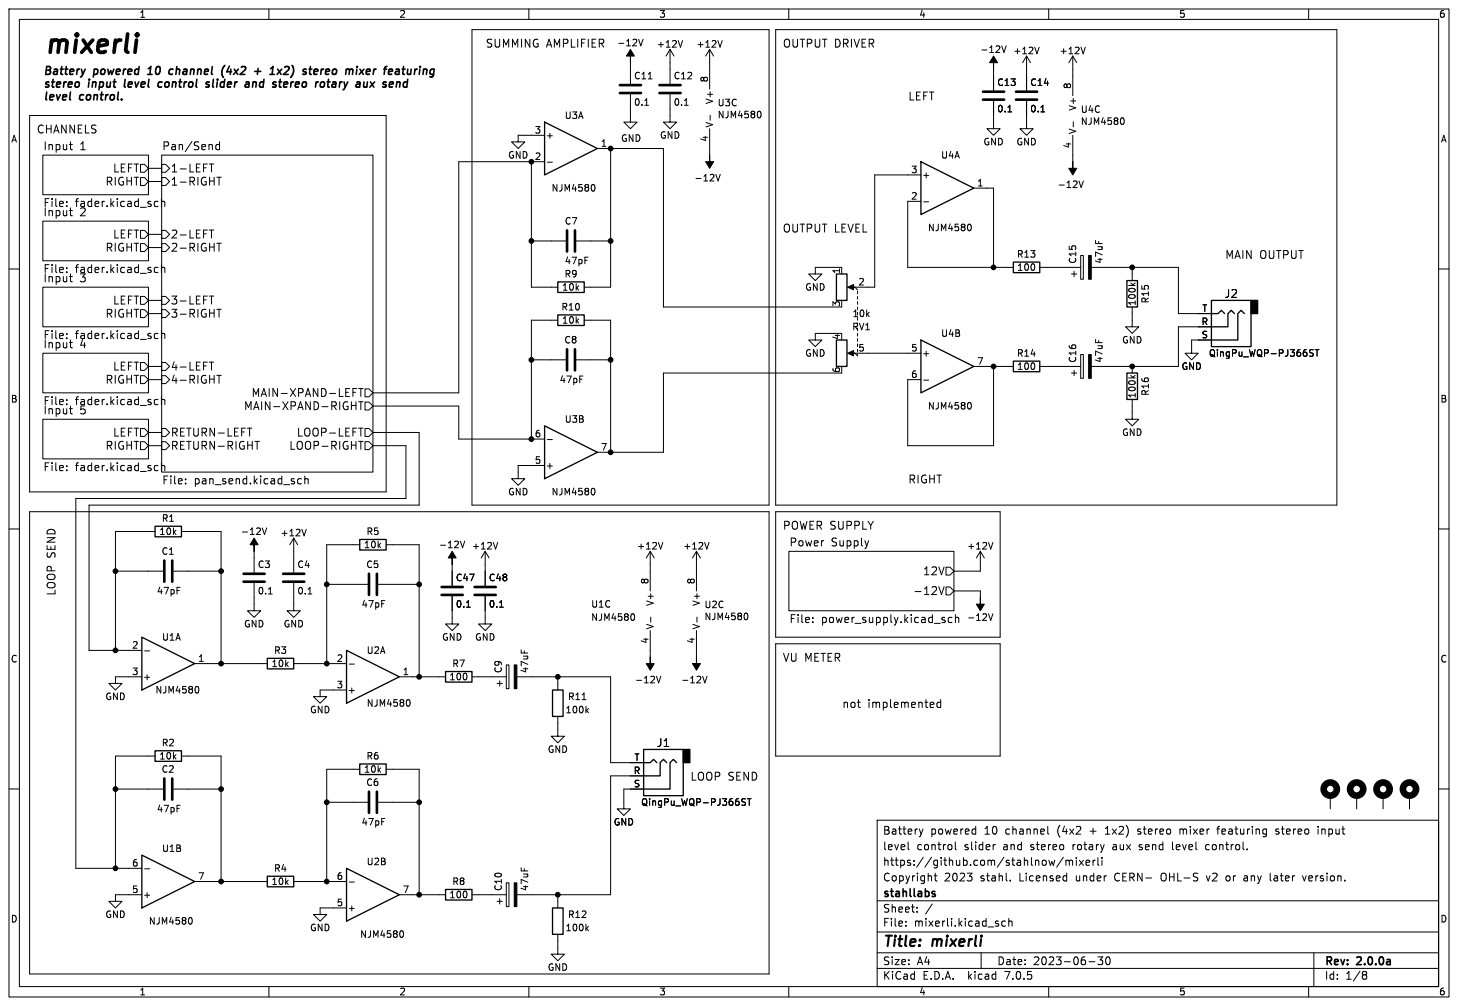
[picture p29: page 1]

Battery powered 10 channel (4x2 + 1x2) stereo mixer featuring
stereo input level control slider and stereo rotary aux send
level control.

MAIN-XPAND-RIGHT MAIN-XPAND-LEFT RETURN-RIGHT RETURN-LEFT Pan/Send File: pan_send.kicad_sch
1-LEFT
1-RIGHT

POWER SUPPLY LOOP SEND

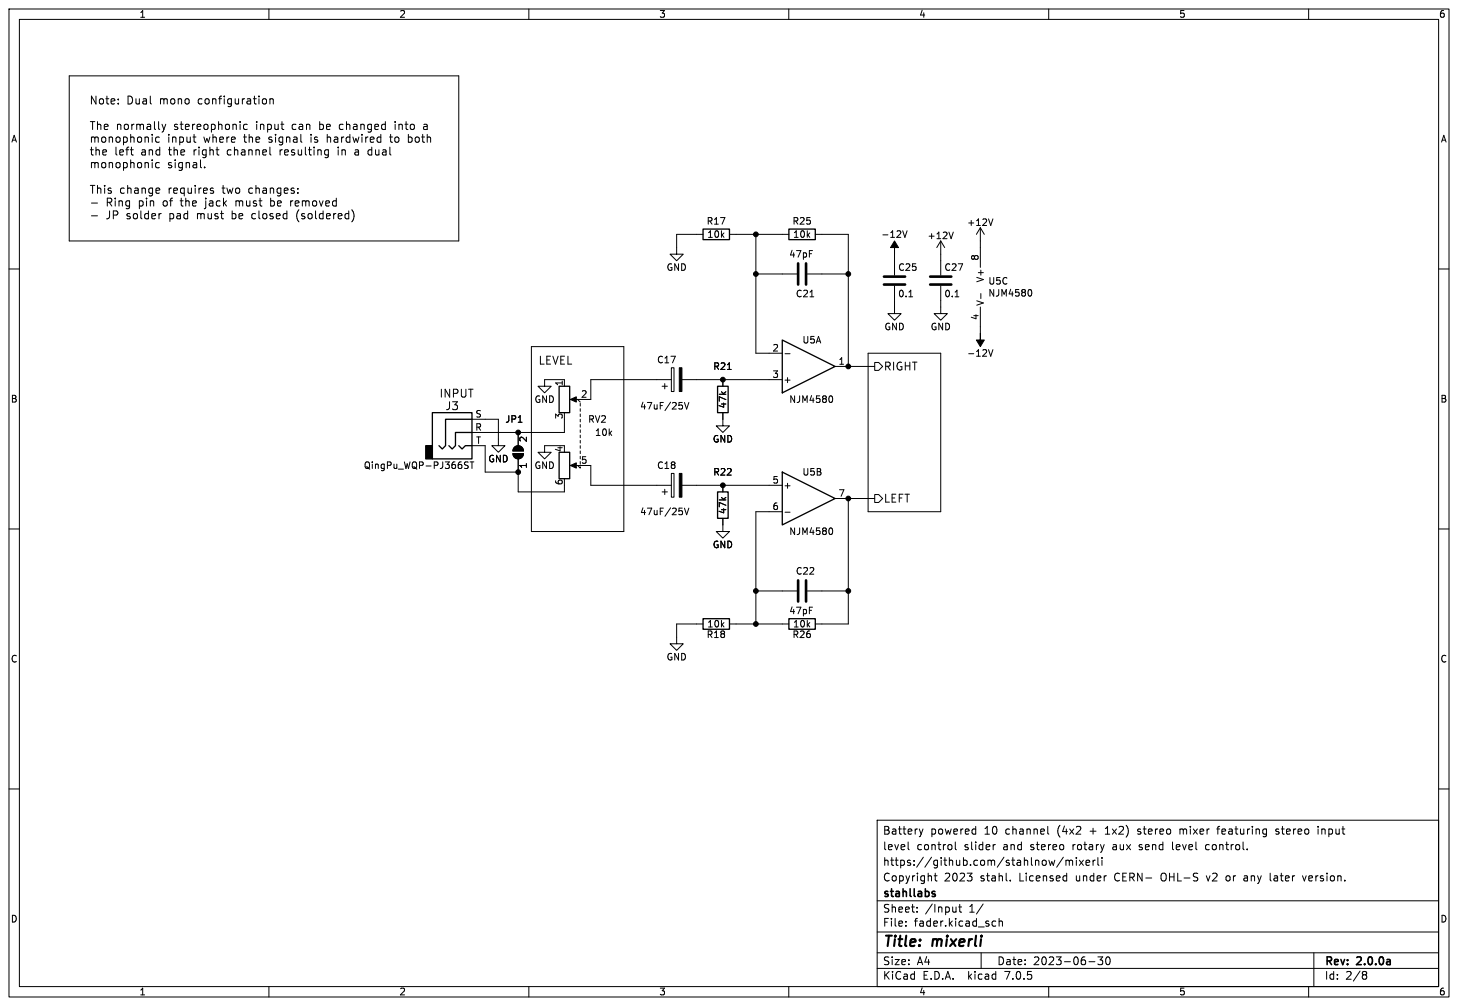
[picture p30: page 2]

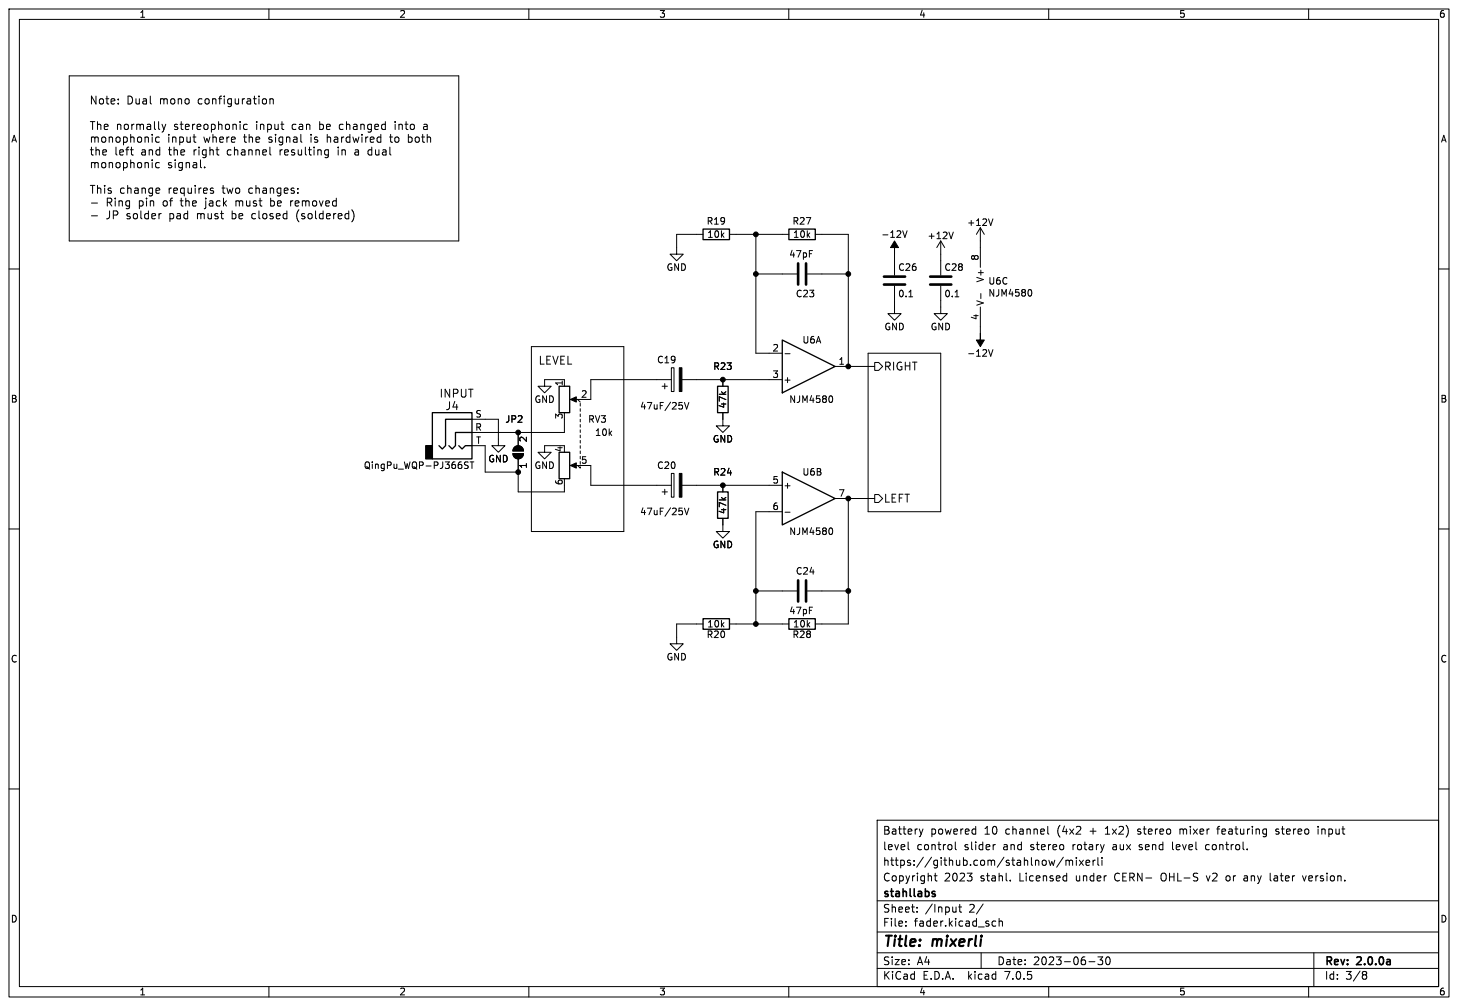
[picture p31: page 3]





LOOP-RIGHT MAIN-XPAND-LEFT
MAIN-XPAND-RIGHT
LOOP-LEFT


https://de.aliexpress.com/item/32789671683.html?spm=a2g0s.9042311.0.0.27424c4d2Mwcoo








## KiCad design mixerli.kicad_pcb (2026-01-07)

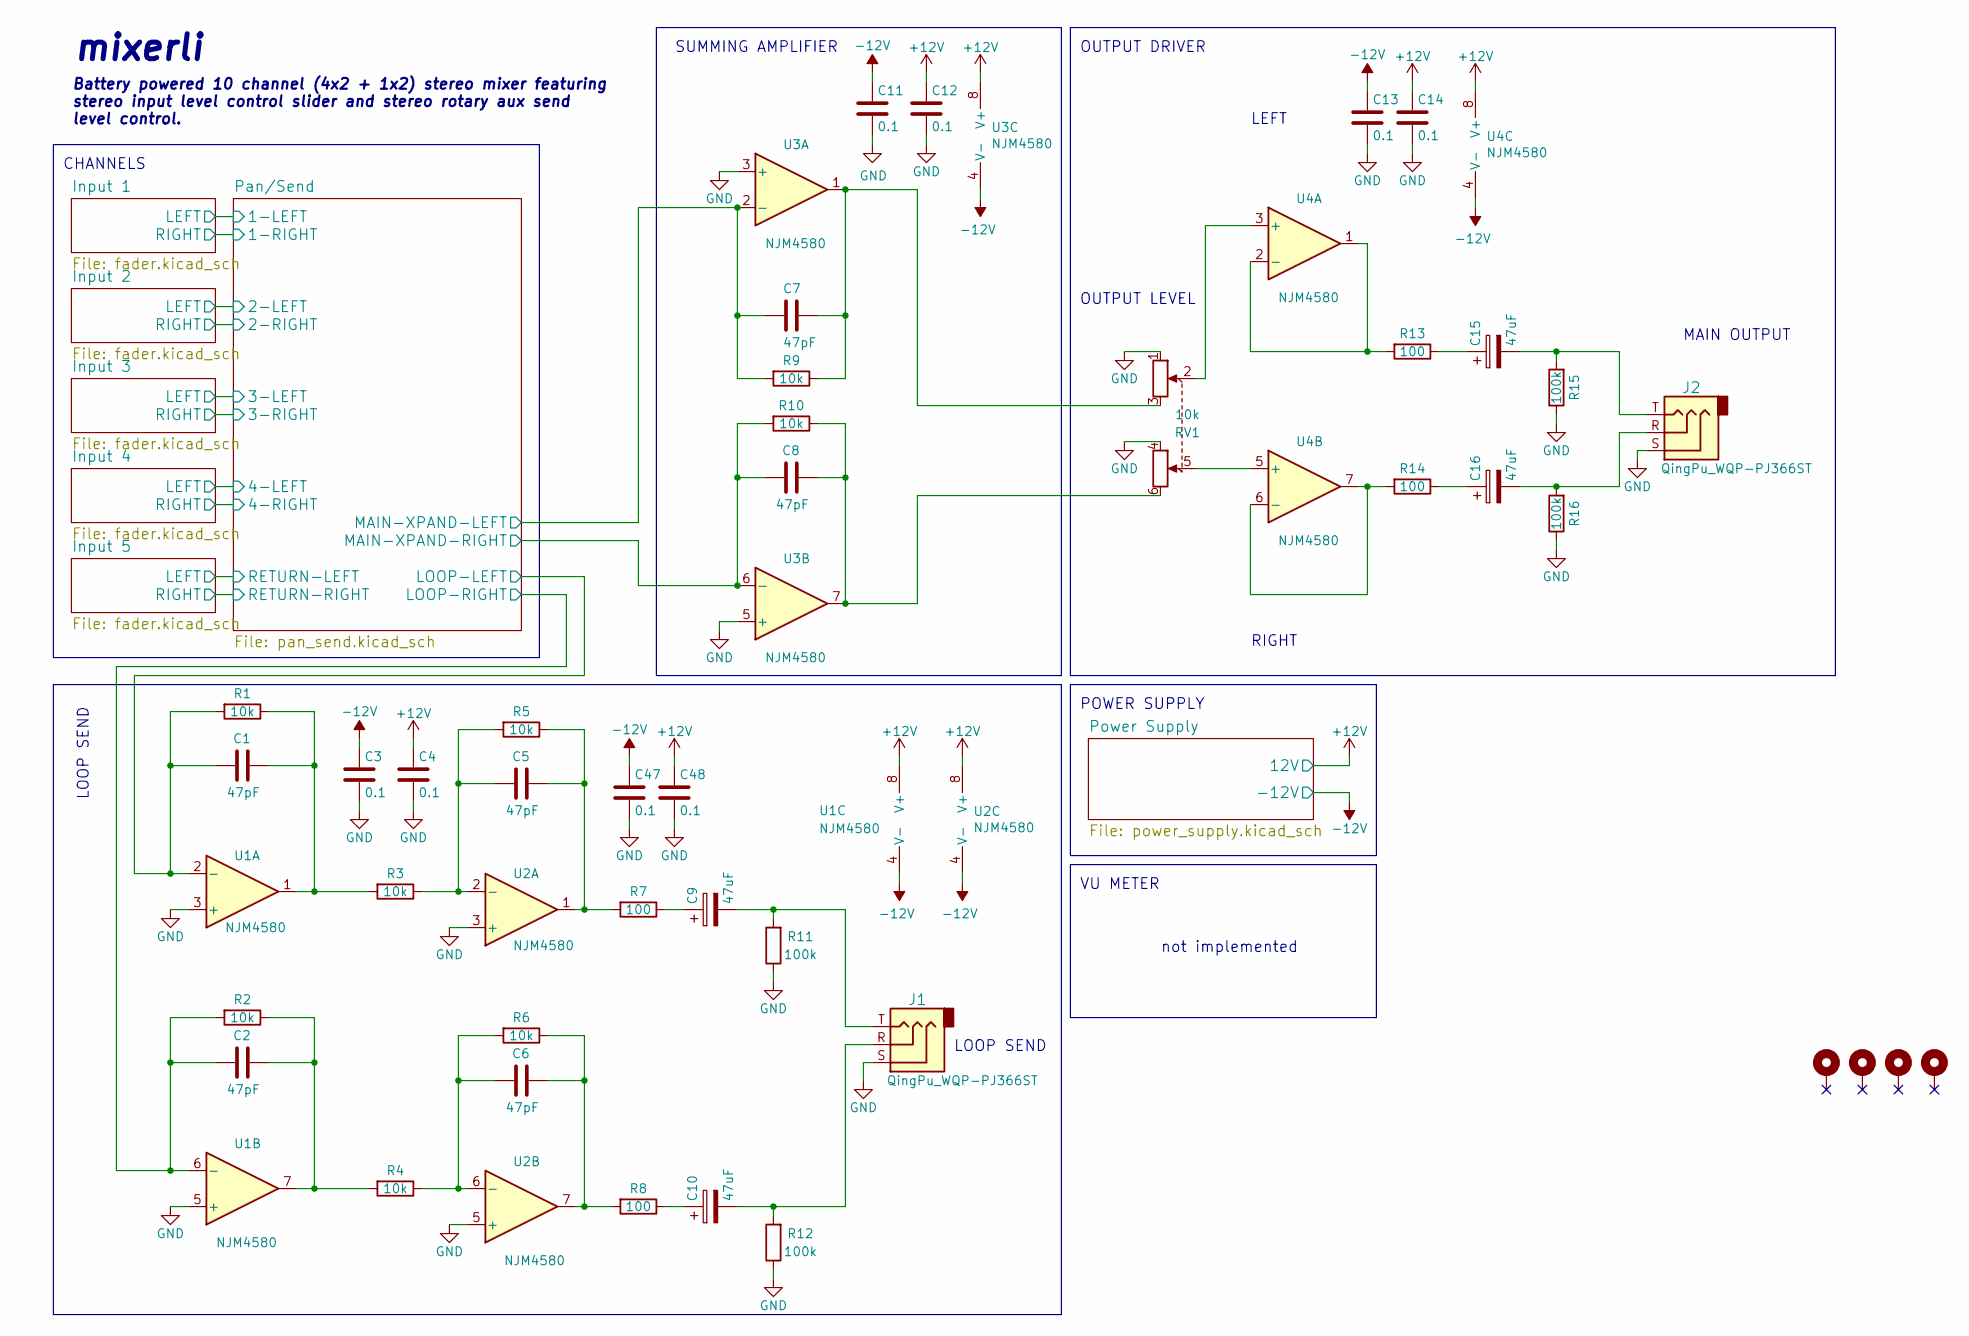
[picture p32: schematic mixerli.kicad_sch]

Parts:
C1, C2, C5, C6, C7, C8: 47pF; C_1206_3216Metric
C3, C4, C11, C12, C13, C14, C47, C48: 0.1; C_1206_3216Metric
C9, C10, C15, C16: 47uF; CP_Elec_5x5.8
H1, H2, H3, H4: MountingHole_Pad; MountingHole_3mm_Pad
J1, J2: QingPu_WQP-PJ366ST; Jack_3.5mm_QingPu_WQP-PJ366ST_Vertical
R1, R2, R3, R4, R5, R6, R9, R10: 10k; R_1206_3216Metric
R7, R8, R13, R14: 100; R_1206_3216Metric
R11, R12, R15, R16: 100k; R_1206_3216Metric
RV1: 10k; RS451121400A
U1, U2, U3, U4: NJM4580; SOIC-8_3.9x4.9mm_P1.27mm

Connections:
+12V: C4.1, C12.1, C14.1, C48.1, U1.8 (V+), U2.8 (V+), U3.8 (V+), U4.8 (V+); also elsewhere on the board
-12V: C3.1, C11.1, C13.1, C47.1, U1.4 (V-), U2.4 (V-), U3.4 (V-), U4.4 (V-); also elsewhere on the board
/Pan/Send/LOOP-LEFT: C1.1, R1.2, U1.2 (-); also elsewhere on the board
/Pan/Send/LOOP-RIGHT: C2.1, R2.2, U1.6 (-); also elsewhere on the board
/Pan/Send/MAIN-XPAND-LEFT: C7.2, R9.2, U3.2 (-); also elsewhere on the board
/Pan/Send/MAIN-XPAND-RIGHT: C8.1, R10.2, U3.6 (-); also elsewhere on the board
GND: C3.2, C4.2, C11.2, C12.2, C13.2, C14.2, C47.2, C48.2, J1.S, J2.S, R11.1, R12.1, R15.1, R16.1, RV1.1, RV1.4, U1.3 (+), U1.5 (+), U2.3 (+), U2.5 (+), U3.3 (+), U3.5 (+); also elsewhere on the board
unnamed: C1.2, R1.1, R3.2, U1.1
unnamed: C2.2, R2.1, R4.2, U1.7
unnamed: C5.2, R5.1, R7.2, U2.1
unnamed: C6.2, R6.1, R8.2, U2.7
unnamed: C7.1, R9.1, RV1.3, U3.1
unnamed: C8.2, R10.1, RV1.6, U3.7
unnamed: C9.1, R7.1
unnamed: C9.2, J1.T, R11.2
unnamed: C10.1, R8.1
unnamed: C10.2, J1.R, R12.2
unnamed: C15.1, R13.1
unnamed: C15.2, J2.T, R15.2
unnamed: C16.1, R14.1
unnamed: C16.2, J2.R, R16.2
unnamed: C5.1, R3.1, R5.2, U2.2 (-)
unnamed: C6.1, R4.1, R6.2, U2.6 (-)
unnamed: RV1.2, U4.3 (+)
unnamed: R13.2, U4.1, U4.2 (-)
unnamed: RV1.5, U4.5 (+)
unnamed: R14.2, U4.6 (-), U4.7

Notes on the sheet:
SUMMING AMPLIFIER
CHANNELS
not implemented
LOOP SEND
OUTPUT LEVEL
mixerli
POWER SUPPLY
VU METER
RIGHT
MAIN OUTPUT
OUTPUT DRIVER
LEFT
Battery powered 10 channel (4x2 + 1x2) stereo mixer featuring stereo input level control slider and stereo rotary aux send level control.

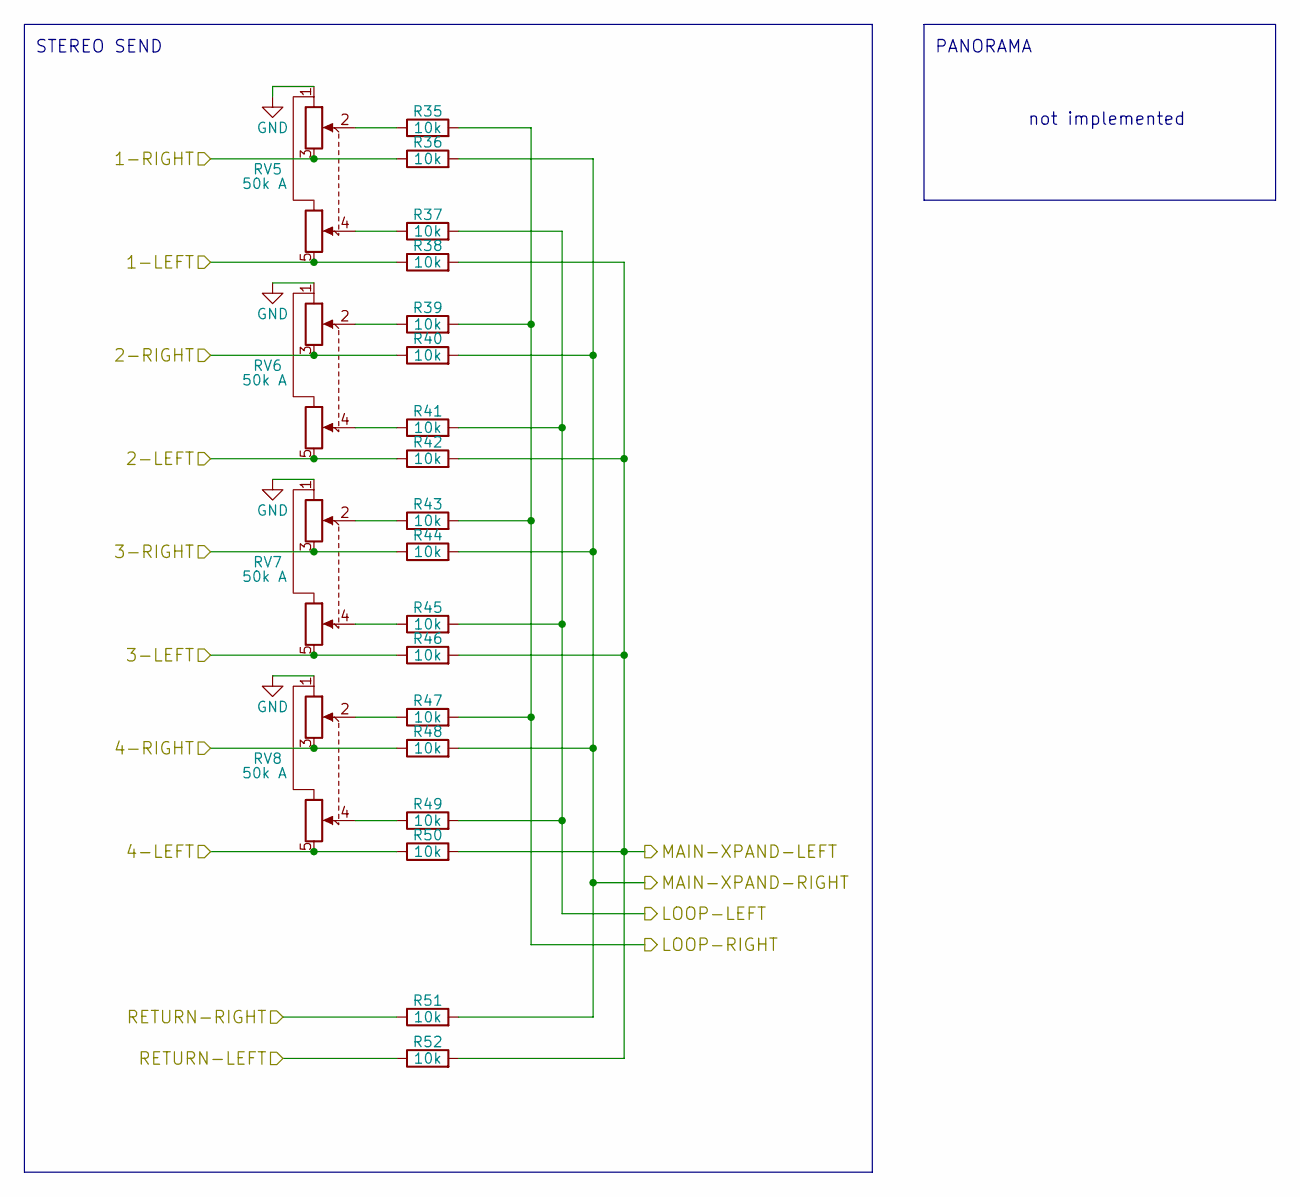
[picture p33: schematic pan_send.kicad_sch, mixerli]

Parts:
R35, R36, R37, R38, R39, R40, R41, R42, R43, R44, R45, R46, R47, R48, R49, R50, R51, R52: 10k; R_1206_3216Metric
RV5, RV6, RV7, RV8: 50k A; RK14K12D0A18

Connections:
/Input 1/LEFT: R38.1, RV5.5; also elsewhere on the board
/Input 1/RIGHT: R36.1, RV5.3; also elsewhere on the board
/Input 2/LEFT: R42.1, RV6.5; also elsewhere on the board
/Input 2/RIGHT: R40.1, RV6.3; also elsewhere on the board
/Input 3/LEFT: R46.1, RV7.5; also elsewhere on the board
/Input 3/RIGHT: R44.1, RV7.3; also elsewhere on the board
/Input 4/LEFT: R50.1, RV8.5; also elsewhere on the board
/Input 4/RIGHT: R48.1, RV8.3; also elsewhere on the board
/Input 5/LEFT: R52.1; also elsewhere on the board
/Input 5/RIGHT: R51.1; also elsewhere on the board
/Pan/Send/LOOP-LEFT: R37.2, R41.2, R45.2, R49.2; also elsewhere on the board
/Pan/Send/LOOP-RIGHT: R35.2, R39.2, R43.2, R47.2; also elsewhere on the board
/Pan/Send/MAIN-XPAND-LEFT: R38.2, R42.2, R46.2, R50.2, R52.2; also elsewhere on the board
/Pan/Send/MAIN-XPAND-RIGHT: R36.2, R40.2, R44.2, R48.2, R51.2; also elsewhere on the board
GND: RV5.1, RV6.1, RV7.1, RV8.1; also elsewhere on the board
unnamed: R35.1, RV5.2
unnamed: R37.1, RV5.4
unnamed: R39.1, RV6.2
unnamed: R41.1, RV6.4
unnamed: R43.1, RV7.2
unnamed: R45.1, RV7.4
unnamed: R47.1, RV8.2
unnamed: R49.1, RV8.4

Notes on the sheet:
STEREO SEND
not implemented
PANORAMA

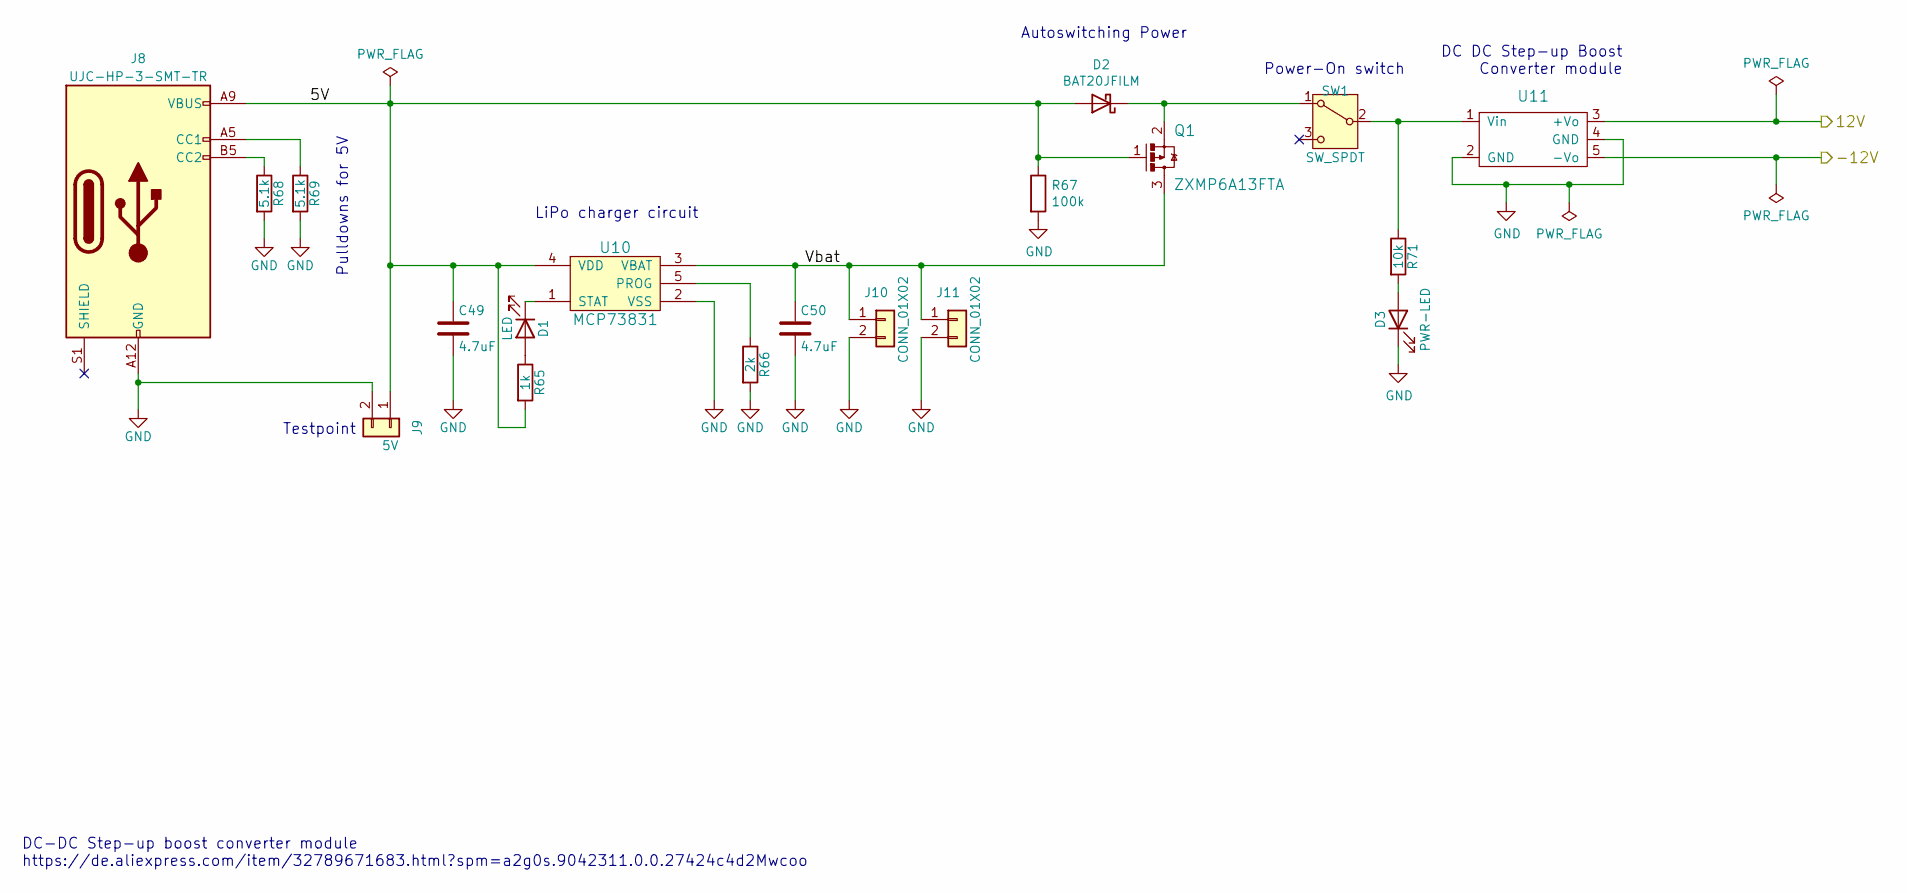
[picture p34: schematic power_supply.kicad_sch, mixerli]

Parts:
C49, C50: 4.7uF; C_1206_3216Metric
D1: LED; LED_Rectangular_W5.0mm_H2.0mm
D2: BAT20JFILM; D_SOD-323
D3: PWR-LED; LED_Rectangular_W5.0mm_H2.0mm
J8: UJC-HP-3-SMT-TR; USB_C_Receptacle_CUI_Devices_UJC-HP-3-SMT-TR
J9: 5V; PinHeader_1x02_P2.54mm_Vertical
J10: CONN_01X02; JST_PH_S2B-PH-K_1x02_P2.00mm_Horizontal
J11: CONN_01X02; PinHeader_1x02_P2.54mm_Vertical
Q1: ZXMP6A13FTA; SOT-23
R65: 1k; R_1206_3216Metric
R66: 2k; R_1206_3216Metric
R67: 100k; R_1206_3216Metric
R68, R69: 5.1k; R_1206_3216Metric
R71: 10k; R_1206_3216Metric
SW1: SW_SPDT; Switches_Alps_SSSS916400
U10: MCP73831; SOT-23-5
U11: DC-DC-Boost-Converter-Positive-Negative-Dual-Outp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; DC-DC-Boost-Converter-Positive-Negative-Dual-Output-Power-S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

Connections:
+12V: U11.3 (+Vo); also elsewhere on the board
-12V: U11.5 (-Vo); also elsewhere on the board
/Power Supply/5V: C49.1, D2.2 (A), J8.A9 (VBUS), J8.B9 (VBUS), J9.1, Q1.1, R65.2, R67.1, U10.4 (VDD)
/Power Supply/Vbat: C50.1, J10.1, J11.1, Q1.3, U10.3 (VBAT)
GND: C49.2, C50.2, D3.1 (K), J8.A12 (GND), J8.B12 (GND), J9.2, J10.2, J11.2, R66.2, R67.2, R68.2, R69.2, U10.2 (VSS), U11.2 (GND), U11.4 (GND); also elsewhere on the board
unnamed: D1.2 (A), R65.1
unnamed: D1.1 (K), U10.1 (STAT)
unnamed: D2.1 (K), Q1.2, SW1.1 (A)
unnamed: D3.2 (A), R71.2
unnamed: J8.A5 (CC1), R69.1
unnamed: J8.B5 (CC2), R68.1
unnamed: R71.1, SW1.2 (B), U11.1 (Vin)
unnamed: R66.1, U10.5 (PROG)

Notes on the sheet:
DC-DC Step-up boost converter module https://de.aliexpress.com/item/32789671683.html?spm=a2g0s.9042311.0.0.27424c4d2Mwcoo
Autoswitching Power
Testpoint
Power-On switch
Pulldowns for 5V
DC DC Step-up Boost Converter module
LiPo charger circuit

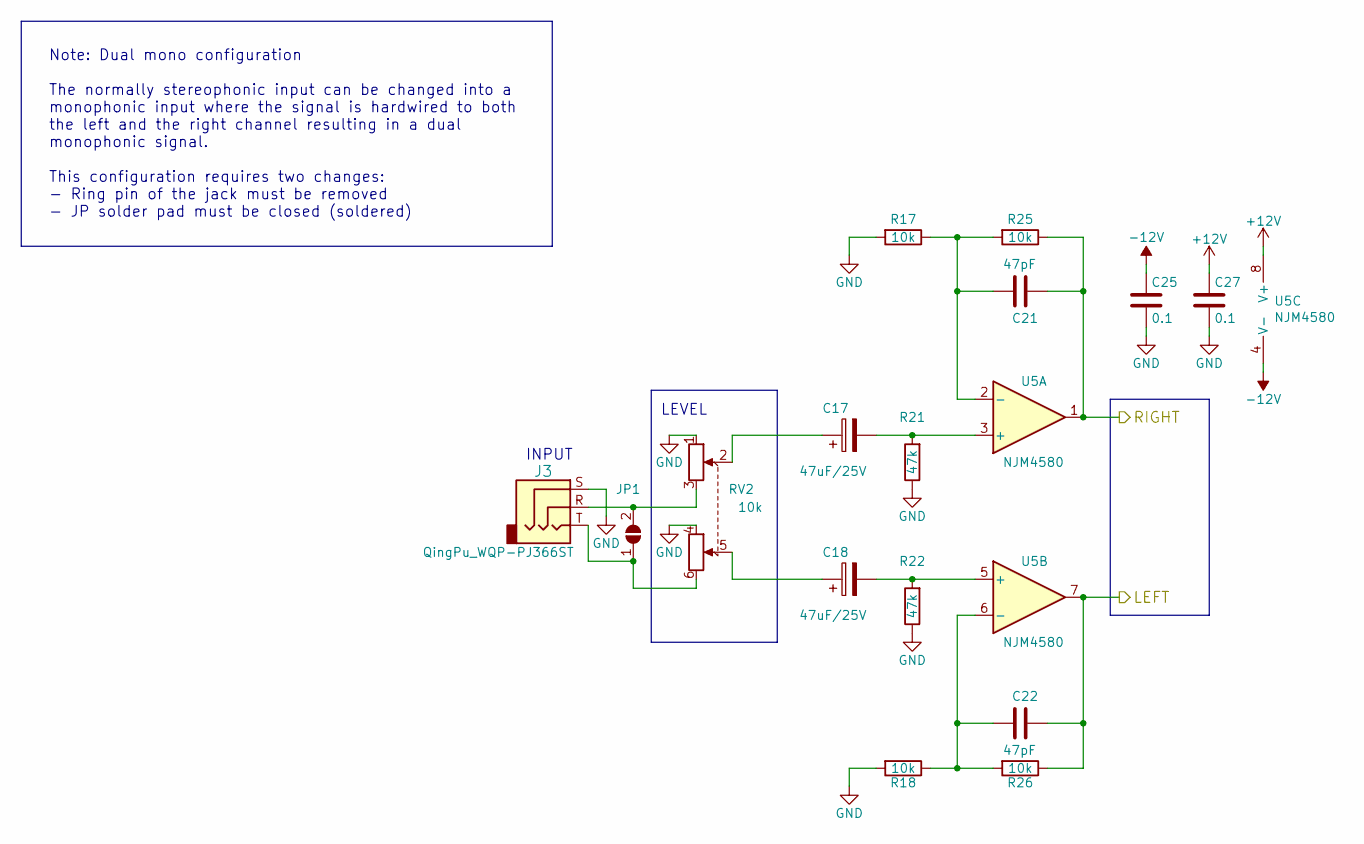
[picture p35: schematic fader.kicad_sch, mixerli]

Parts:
C17, C18: 47uF/25V; CP_Elec_5x5.8
C21, C22: 47pF; C_1206_3216Metric
C25, C27: 0.1; C_1206_3216Metric
J3: QingPu_WQP-PJ366ST; Jack_3.5mm_QingPu_WQP-PJ366ST_Vertical
JP1: SolderJumper_2_Open; SolderJumper-2_P1.3mm_Open_TrianglePad1.0x1.5mm
R17, R18, R25, R26: 10k; R_1206_3216Metric
R21, R22: 47k; R_1206_3216Metric
RV2: 10k; RS451121400A
U5: NJM4580; SOIC-8_3.9x4.9mm_P1.27mm

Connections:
+12V: C27.1, U5.8 (V+); also elsewhere on the board
-12V: C25.1, U5.4 (V-); also elsewhere on the board
/Input 1/LEFT: C22.1, R26.1, U5.7; also elsewhere on the board
/Input 1/RIGHT: C21.1, R25.1, U5.1; also elsewhere on the board
GND: C25.2, C27.2, J3.S, R17.2, R18.2, R21.1, R22.1, RV2.1, RV2.4; also elsewhere on the board
unnamed: C17.1, RV2.2
unnamed: C18.1, RV2.5
unnamed: J3.T, JP1.1 (A), RV2.6
unnamed: J3.R, JP1.2 (B), RV2.3
unnamed: C17.2, R21.2, U5.3 (+)
unnamed: C21.2, R17.1, R25.2, U5.2 (-)
unnamed: C18.2, R22.2, U5.5 (+)
unnamed: C22.2, R18.1, R26.2, U5.6 (-)

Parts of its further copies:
C19, C20, C29, C30, C35, C36, C41, C42: 47uF/25V; CP_Elec_5x5.8
C23, C24, C31, C32, C37, C38, C43, C44: 47pF; C_1206_3216Metric
C26, C28, C33, C34, C39, C40, C45, C46: 0.1; C_1206_3216Metric
J4, J5, J6, J7: QingPu_WQP-PJ366ST; Jack_3.5mm_QingPu_WQP-PJ366ST_Vertical
JP2, JP3, JP4, JP5: SolderJumper_2_Open; SolderJumper-2_P1.3mm_Open_TrianglePad1.0x1.5mm
R19, R20, R27, R28, R29, R30, R33, R34, R53, R54, R57, R58, R59, R60, R63, R64: 10k; R_1206_3216Metric
R23, R24, R31, R32, R55, R56, R61, R62: 47k; R_1206_3216Metric
RV3, RV4, RV9, RV10: 10k; RS451121400A
U6, U7, U8, U9: NJM4580; SOIC-8_3.9x4.9mm_P1.27mm

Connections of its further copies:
+12V: C28.1, C34.1, C40.1, C46.1, U6.8 (V+), U7.8 (V+), U8.8 (V+), U9.8 (V+); also elsewhere on the board
-12V: C26.1, C33.1, C39.1, C45.1, U6.4 (V-), U7.4 (V-), U8.4 (V-), U9.4 (V-); also elsewhere on the board
/Input 2/LEFT: C24.1, R28.1, U6.7; also elsewhere on the board
/Input 2/RIGHT: C23.1, R27.1, U6.1; also elsewhere on the board
/Input 3/LEFT: C32.1, R34.1, U7.7; also elsewhere on the board
/Input 3/RIGHT: C31.1, R33.1, U7.1; also elsewhere on the board
/Input 4/LEFT: C38.1, R58.1, U8.7; also elsewhere on the board
/Input 4/RIGHT: C37.1, R57.1, U8.1; also elsewhere on the board
/Input 5/LEFT: C44.1, R64.1, U9.7; also elsewhere on the board
/Input 5/RIGHT: C43.1, R63.1, U9.1; also elsewhere on the board
GND: C26.2, C28.2, C33.2, C34.2, C39.2, C40.2, C45.2, C46.2, J4.S, J5.S, J6.S, J7.S, R19.2, R20.2, R23.1, R24.1, R29.2, R30.2, R31.1, R32.1, R53.2, R54.2, R55.1, R56.1, R59.2, R60.2, R61.1, R62.1, RV3.1, RV3.4, RV4.1, RV4.4, RV9.1, RV9.4, RV10.1, RV10.4; also elsewhere on the board
unnamed: C19.1, RV3.2
unnamed: C20.1, RV3.5
unnamed: C29.1, RV4.2
unnamed: C30.1, RV4.5
unnamed: C35.1, RV9.2
unnamed: C36.1, RV9.5
unnamed: C41.1, RV10.2
unnamed: C42.1, RV10.5
unnamed: J4.T, JP2.1 (A), RV3.6
unnamed: J4.R, JP2.2 (B), RV3.3
unnamed: J5.T, JP3.1 (A), RV4.6
unnamed: J5.R, JP3.2 (B), RV4.3
unnamed: J6.T, JP4.1 (A), RV9.6
unnamed: J6.R, JP4.2 (B), RV9.3
unnamed: J7.T, JP5.1 (A), RV10.6
unnamed: J7.R, JP5.2 (B), RV10.3
unnamed: C19.2, R23.2, U6.3 (+)
unnamed: C23.2, R19.1, R27.2, U6.2 (-)
unnamed: C20.2, R24.2, U6.5 (+)
unnamed: C24.2, R20.1, R28.2, U6.6 (-)
unnamed: C29.2, R31.2, U7.3 (+)
unnamed: C31.2, R29.1, R33.2, U7.2 (-)
unnamed: C30.2, R32.2, U7.5 (+)
unnamed: C32.2, R30.1, R34.2, U7.6 (-)
unnamed: C35.2, R55.2, U8.3 (+)
unnamed: C37.2, R53.1, R57.2, U8.2 (-)
unnamed: C36.2, R56.2, U8.5 (+)
unnamed: C38.2, R54.1, R58.2, U8.6 (-)
unnamed: C41.2, R61.2, U9.3 (+)
unnamed: C43.2, R59.1, R63.2, U9.2 (-)
unnamed: C42.2, R62.2, U9.5 (+)
unnamed: C44.2, R60.1, R64.2, U9.6 (-)

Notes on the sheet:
INPUT
LEVEL
Note: Dual mono configuration The normally stereophonic input can be changed into a monophonic input where the signal is hardwired to both the left and the right channel resulting in a dual monophonic signal. This configuration requires two changes: - Ring pin of the jack must be removed - JP solde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

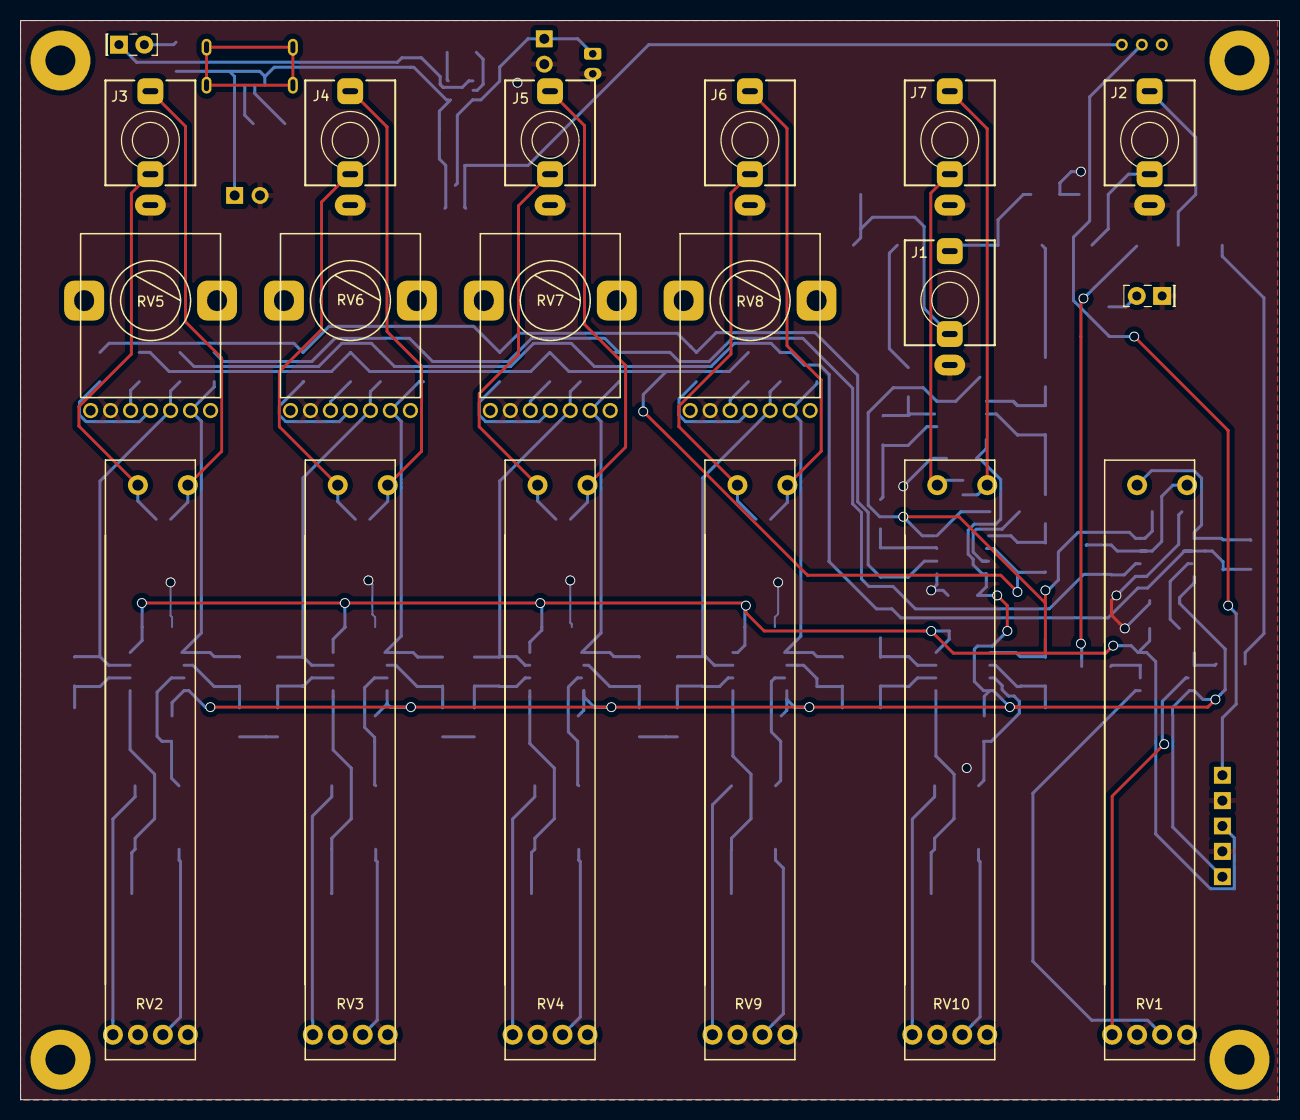
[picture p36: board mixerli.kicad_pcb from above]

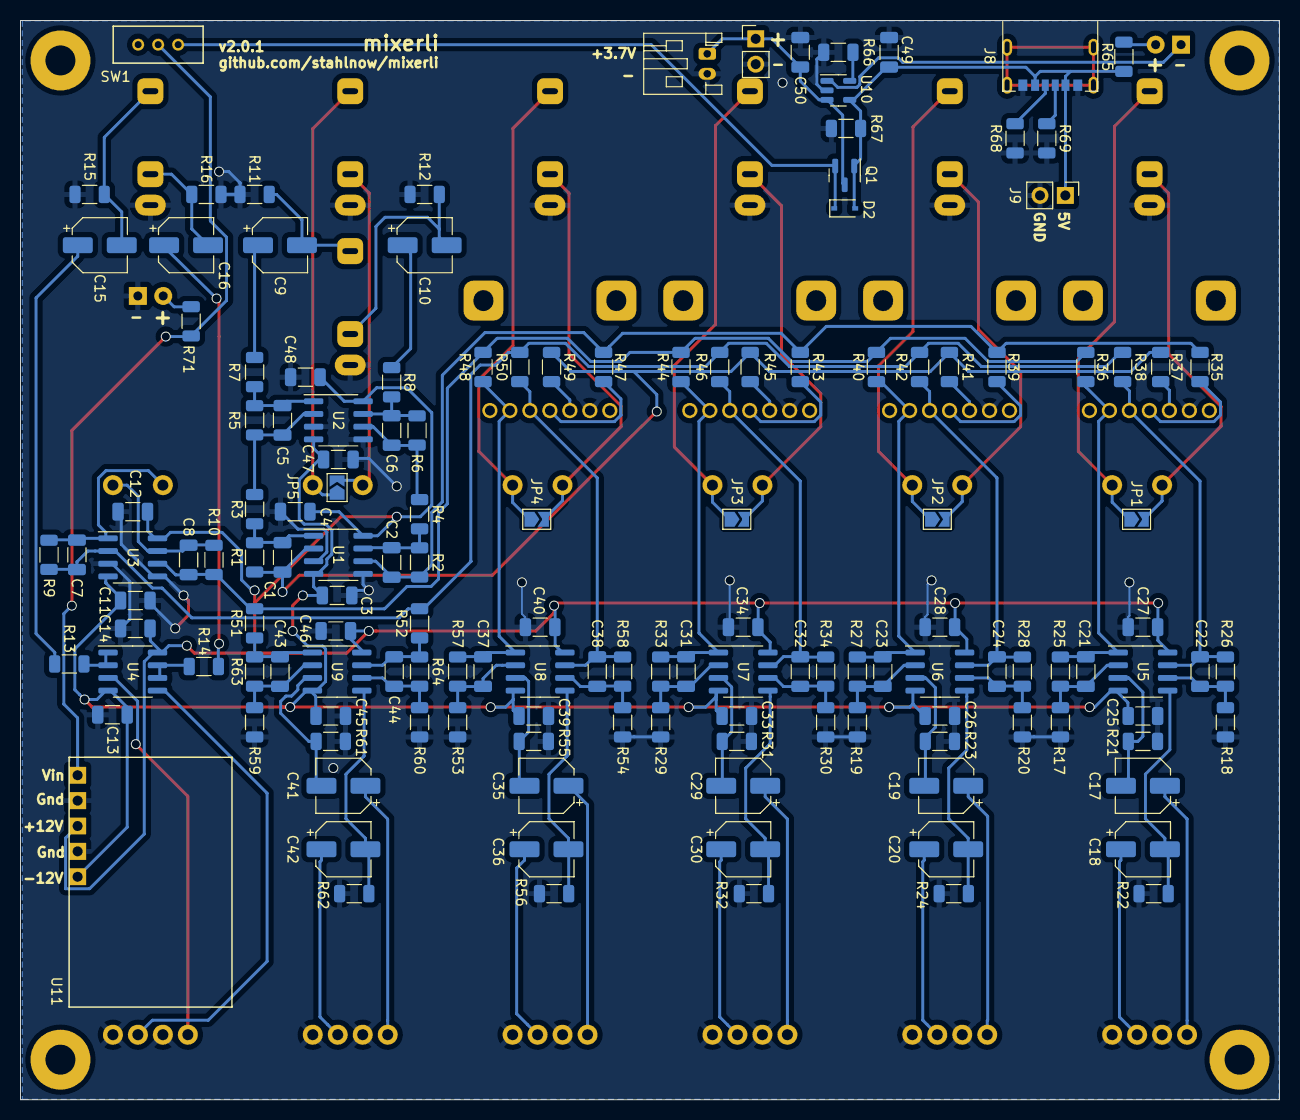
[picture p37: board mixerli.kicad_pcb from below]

Board: 2 copper layers, 126.0 x 108.0 mm, 166 parts (143 on the bottom side), 95 nets.

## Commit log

2018-02-25 :rocket: take off
    [1050170001.stp, S2B-PH-SM4-TB.STEP, Turn knob.STEP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]
2019-01-27 update to kicad version 5, bug fix layout
    [inputs_1-3-2018-08-09-14-19-03.sch, inputs_1-3-2018-08-28-06-15-16.sch, inputs_1-3.sch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]
2022-04-05 :rocket: 2.0.0
    [fader.kicad_sch, fader.sch, inputs_1-3-2018-08-09-14-19-03.sch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]
2022-05-26 holes, jst bat, ..
    [fader.kicad_sch, mixerli.kicad_pcb, mixerli.kicad_sch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]
2022-08-25 mixerli 2.0.0 alpha
    [mixerli-B_Cu.gbr, mixerli-B_Mask.gbr, mixerli-B_Paste.gbr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]
2023-05-13 documentation / update kicad
    [mixerli.kicad_pcb, mixerli.kicad_sch, power_supply.kicad_sch]
2023-05-13 link to build guide and schematics
2023-06-30 update LICENSE
    [fader.kicad_sch, mixerli.kicad_sch, pan_send.kicad_sch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]
2023-06-30 tidy up..
    [fader.sch, inputs_1-3.sch, inputs_4_return.sch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]
2023-07-02 gerber 2.0.0 final
    [mixerli-B_Cu.gbr, mixerli-B_Mask.gbr, mixerli-B_Paste.gbr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]
2023-07-02 layout postscript
    [mixerli.kicad_pcb]
2023-07-03 fix potentiometer holes NPTH -> through hole
    [mixerli.kicad_pcb]
2023-08-11 added erratum for pull-down resistors
    [power_supply.kicad_sch]
2023-08-11 case update
    [1050170001.stp, S2B-PH-SM4-TB.STEP, Turn knob.STEP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]
2023-08-11 backups, move 3d stuff
    [1050170001.stp, S2B-PH-SM4-TB.STEP, Turn knob.STEP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]
2024-08-06 v2.0.1: fixed pulldown resistors
    [fader.kicad_sch, mixerli.kicad_pcb, mixerli.kicad_sch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]
2024-08-06 gerber v2.0.1
2024-12-24 metal sheet enclosure for 2.0 (charge led cutout missing!)
    [1050170001.stp, S2B-PH-SM4-TB.STEP, Turn knob.STEP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]
2026-01-07 metalsheet enclosure
    [mixerli_v2.0.0-bottom.step, mixerli_v2.0.0-top.step, mixerli_v2.0.0.FCStd]
2026-01-07 kicad 9
    [fader.kicad_sch, mixerli.kicad_pcb, mixerli.kicad_sch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]

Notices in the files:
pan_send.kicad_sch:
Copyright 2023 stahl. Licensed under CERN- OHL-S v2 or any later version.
